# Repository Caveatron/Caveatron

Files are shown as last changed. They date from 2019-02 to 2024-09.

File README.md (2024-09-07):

# Caveatron

The Caveatron is a unique compact, handheld, electronic device for mapping caves or other underground environments. It functions as a cave survey tool, recording conventional distance, azimuth and inclination measurements and can also go far beyond that with its integrated LIDAR to capture a full 3D scan of the cave interior. It greatly speeds up the cave survey process by recording station-to-station shots in just a few seconds and performs a station-to-station 3D scan traverse in less than a minute. The user can fully interact with the device and review data with the built-in touchscreen. A USB port provides access to the stored data from a PC or Mac and is also used to charge the integrated long-life battery pack. The station measurement file is compatible with Walls Cave Mapping Software and the LIDAR scan file can be quickly processed into a standard point cloud with custom-written software. The Caveatron is designed to be easily portable, lightweight, and low cost as well as water and dirt resistant and durable enough to survive regular use in a cave.

## Key Features

- Survey and 3D scan caves
- 12 m or 30 m LIDAR range at up to 32000 pts/sec
- Laser rangefinder up to 40 m
- Integrated intertial measurement unit including digital compass, inclinometer, and gyroscope
- Position estimation during scanning
- Fast Teensy processor
- File transfer to PC over USB
- Water/dust resistant 3D printed enclosure
- Custom printed circuit board

## What's New (2024-05-03)

Rev C is the current and preferred version and is the only one in active development. This version uses the faster Teensy 4.1 processor and has several enhancements including ability to use the 30m RPLIDAR S2 or 12 RPLIDAR A1M8, a new magnetometer module for much improved compass accuracy and reliability, a capacitive touchscreen, faster battery charging, and a smaller size.
New revisions of the Rev C board (C.3 and C.4) have been posted along with an updated bill of materials. The Rev C assembly documentation has not yet been updated for the new PCBs but is not significantly different.

Rev B is based on the older Teensy 3.6 processor and is now deprecated and some components may no longer be available.

The original, Arduino Due-based version (Rev A) information is all still available and can now be found in the legacy_material_rev-A directory.
In the Rev A version, many people had difficulty with compiling the code in terms of getting all the libraries to work together and getting all the settings right. With the Teensy, it is relatively easy to load a pre-compiled HEX file, avoiding all the software headaches. For now I am just going to provide the HEX file instead of all the code to simplify things, since the code has gotten even more complex in the new version and I am no longer using the Arduino IDE. If you want to work on the code, please contact me directly.

## Summary of Caveatron Directory Contents for each Revision

### Documentation
- Bill of Materials
- Assembly Instructions
- Wire Harness Assembly Instructions
- 3D Printed Parts Description

### PCB
- Schematic diagram
- KiCad files
- PCB gerber files

### Mechanical
- STL files for all 3D printed parts
- STEP files for all 3D printed parts

## These items can be found in other folders:

### Calibration
Info and calculators can be found at https://github.com/Caveatron/Calibration

### Software
Software can be found at https://github.com/Caveatron/Software

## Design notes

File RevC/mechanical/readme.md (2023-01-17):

These STL files contain a full design for the new Caveatron Rev C enclosure with either an RPLIDAR S2 or RPLIDAR A1M8. All parts have been printed and tested. STEP files are also provided for customization.

Two versions exist of the RPLIDAR S2 lid. The DOME version uses an acrylic dome to ensure a fully protective and waterproof cover. This version may reduce the range but has not beeen tested to detemine what the effect is. The OPEN version exposes part of the LIDAR head and uses a gasket to seal against to RPLIDAR body. This provides an unobstructed view from the LIDAR and it may provide a waterproof seal as well but has not been tested and does leave the LIDAR partially exposed to impacts. 

Similarly, two versions of the RPLIDAR A1M8 lid are provided including one with windows and one that only has metal corner posts but leaves the sides open to minimize obstructions and prevent distortions. The open version only provides impact protection as it will allow dust, mud or water into the enclosure. 

A detailed assembly document will be uploaded when completed.

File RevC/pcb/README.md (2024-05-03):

# Caveatron Printed Circuit Boards (PCBs)

This folder provides the files needed to create PCBs for the Caveatron. I use PCBWay for fabrication and the Gerber files are setup for their requirements. For each board version, the following are providedL
- Gerber files: Send these to the PCB fabricator to get your board produced. Nothing else should be needed.
- Kicad files: The files for the schematic and board layout if you need to make an edit.
- PDF of the circuit schematic

## What is the difference between the PCB revisions?

### Rev C.4
This is the preferred board version. Use this one for most builds.

### Rev C.3
Use this version if want to use the Pololu MinIMU or AltIMU modules to provide all of the IMU data and not use the RM3100. This is lower cost but will result in lower quality azimuth data. You can also use this version if you want to use the MinIMU or AltIMU modules to provide just the accelerometer and gyroscope data alongside using the RM3100 for the magnetometer.

### Rev C.2
Use this version if you want to use a coin cell battery to maintain the RTC, although the battery will have to be replaced every 6 weeks. Can be upgraded to replace coin cell with modification. It is otherwise the same as C.3. Not recommended.

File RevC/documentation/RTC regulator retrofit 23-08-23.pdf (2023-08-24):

## RTC Regulator Retrofit for Caveatron/Caveatron SV Rev C

### Version: 2023-08-23

Background

The Teensy 4.1 Real-Time Clock (RTC) draws much more current than the one in the Teensy 3.6 (46uA vs 1.6uA). As a result, the CR1220 battery used for backup power will only last about 6 weeks. Since such frequent replacement is undesirable, I have created a retrofit for the Rev C Caveatron and Caveatron SV that replaces the battery with a small voltage regulator that ties directly to the main battery. Without recharge, this will keep the RTC powered for more than 5 years. Although the RTC is nominally powered by 3V, it runs fine to below 2.7 V. Since 2.8V is the nominal cutoff for the main battery, that was selected for the voltage regulator. The one used has a very low drop out voltage that is nearly the same as its output voltage when at or below 2.8V, so can be used all through the main battery’s voltage range.

The required materials are in the table at the end of this document. The circuit is shown below and contains a simple voltage regulator, two capacitors and input/output pins. The 1 uF ceramic capacitors are placed across the input and output terminals of the regulator for stability. A JST connector is used for the input voltage which is provided by wires that are soldered to the input of the battery charger module. The circuit board will be soldered to the pads that were used for the coin cell battery holder to provide the output voltage to the RTC. Two right angle header pins on either side of the board are used for this purpose (two on each side allow it to sit flat on the board and make it easier to solder.)

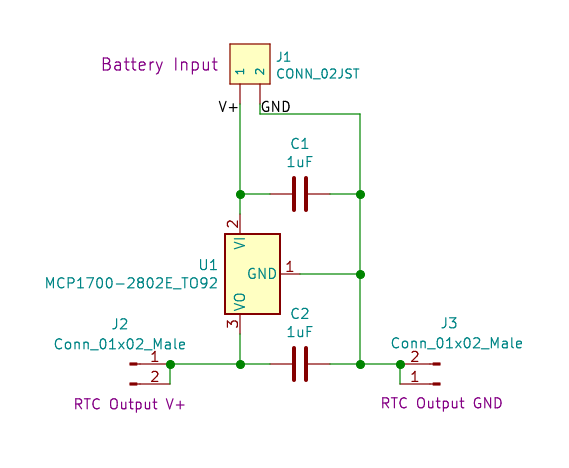
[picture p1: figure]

Assemble the voltage regulator board

1. Cut a piece of protoboard to 0.6 x 0.6 inches, cutting between the holes

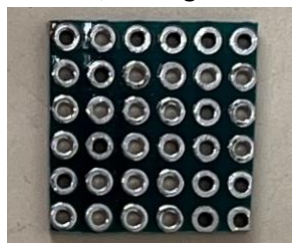
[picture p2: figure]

2. Insert the regulator and capacitors through the holes on the protoboard as shown in the photo. Be sure that the regulator flat is oriented correctly. When looking at the regulator from the flat side, the ground pin is on the left.

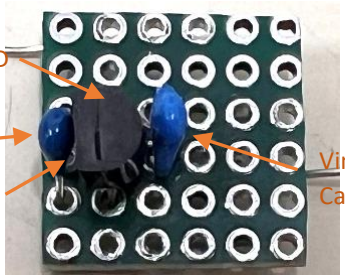
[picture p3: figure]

3. On the underside of the protoboard, bend the pins and wrap them together as shown in the photo below with the pin wires labeled. Be sure the pins are bent to pass adjacent to the holes that will be used for the right angle headers (orange circles) and the JST connector (blue circles).

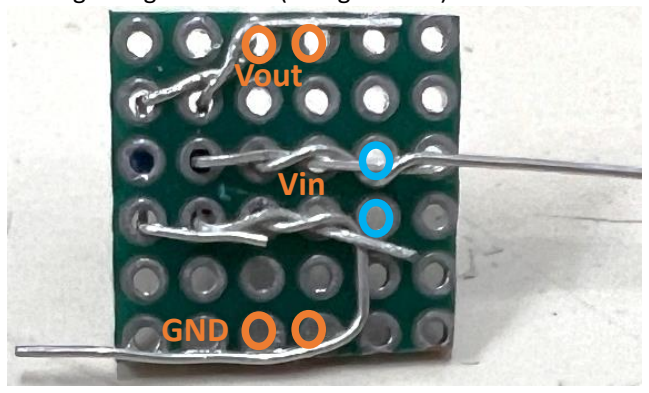
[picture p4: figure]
GND; Vin; Vout

4. Solder the wrapped pin wires together.
5. Cut the right angle headers so you have two sets with two pins each.
6. Slide the plastic standoff on the header down to where it is near the end of the pin
7. Insert the right angle headers into the center two holes on opposite edges of the board as shown in the photo below. Be sure the right angle part is underneath the board and the plastic standoffs are sticking out. Also be sure the pin wires from the components are touching the header pins on the underside of the board
8. Ensuring the right angle header pins are not angled to the board and sticking straight out, solder them to the wire pins.

### Regulator Flat

### GND

### Vin to GND Capacitor

### Vout to GND Capacitor

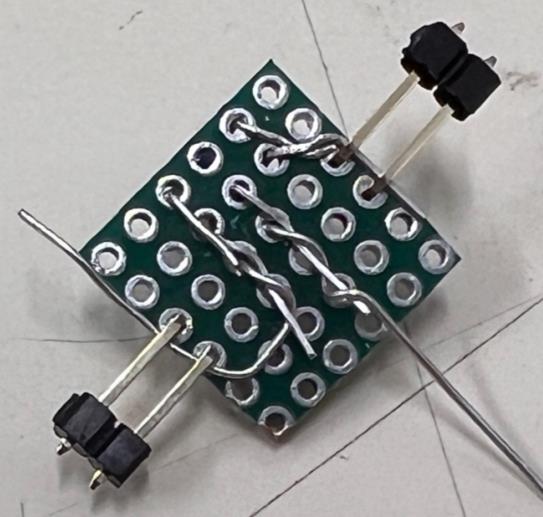
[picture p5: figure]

9. Insert the JST socket – be sure it is oriented so that the red wire on the connector will connect to the voltage input of the regulator (center pin when viewed from the flat side.)
10. Solder the JST socket pins to the pin wires on the underside of the board. Trim off any excess wire.
11. If desired, you can test the board by applying 3-5V on the JST connector and confirming 2.8V is present between the two sets of right-angle header pins
12. Cut the right angle header pins to remove the plastic standoff and shorten them so that the length beyond the board is about 0.1” as shown in the photos below.

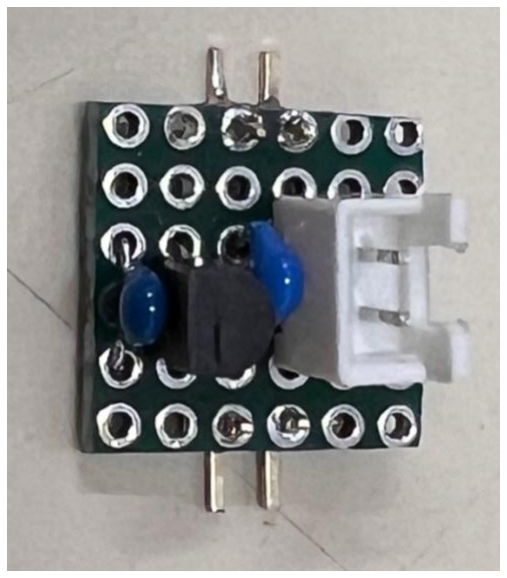
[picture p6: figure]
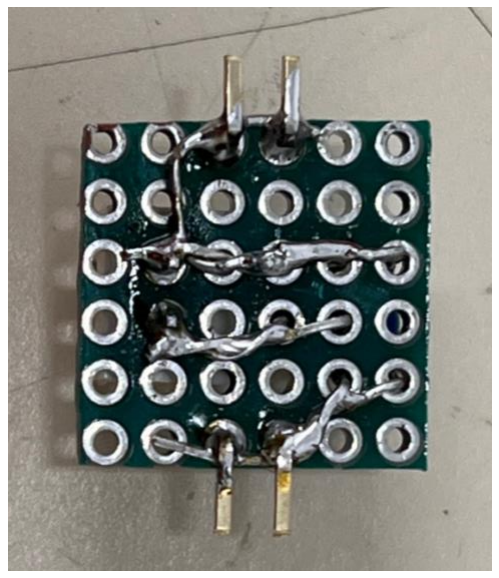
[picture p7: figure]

Finished RTC regulator board

Replace the coin cell battery holder

1. Using a small flathead screwdriver, gently pry on the inside of the coin cell battery holder [A in figure below] while holding the soldering iron on the pad until it comes up from the solder. The pull up on the holder while holding the soldering iron on the other side until it come free. Clean up excess solder on the RTC coin cell pads.

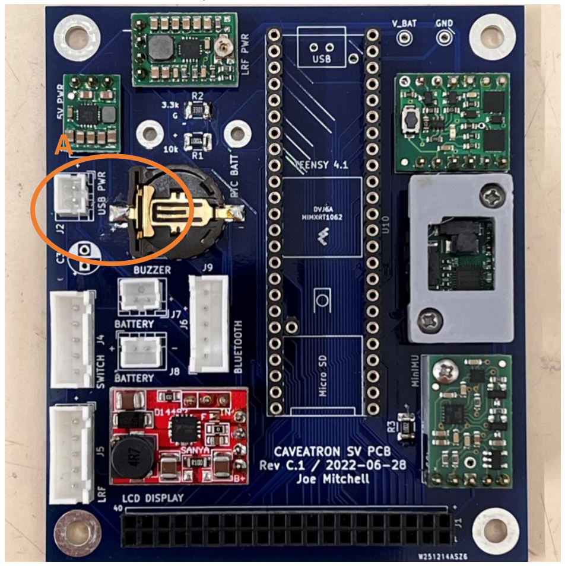
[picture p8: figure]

Caveatron SV PCB before modification. The location on the regular Caveatron is different but the process is the same.

2. Position the regulator circuit across the pads [B (Vout) & C (GND) in the figure below] and center the header pins on the pads as best as possible. Verify that the ground of the regulator board is toward the negative RTC pad [C] (the pad to the left when looking toward the flat of the regulator.)
3. Holding the circuit board in place, solder it to the RTC pads.

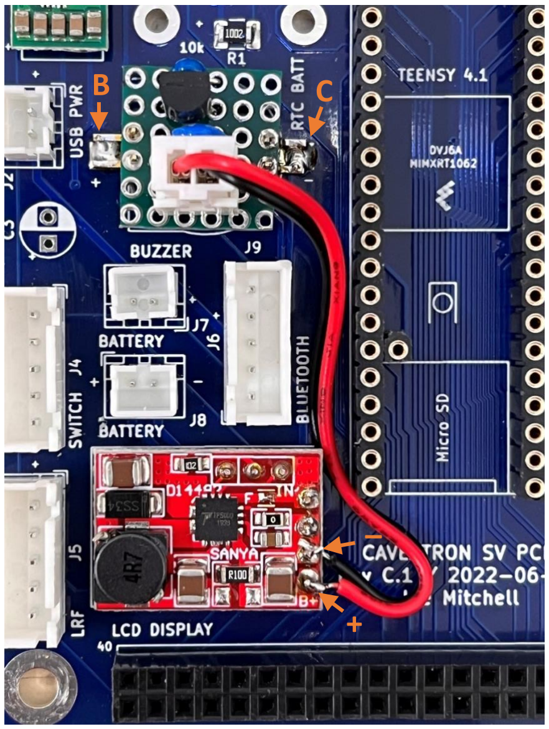
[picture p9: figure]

Installed RTC regulator board connected to the battery.

Connect to the supply voltage

1. Locate the battery charger module. The two indicated pins [+, -] on the illustration above are connected directly to the battery.
2. Place the black wire touching the GND input pin [-] on the top of the battery charger module and carefully solder it so that it does not touch any other pad or pin.
3. Repeat with the red wire on the Vin pin [+].
4. Check that the connection is good and that you have the battery voltage (3-4.2V) on the JST connector.
5. Plug the JST connector into the voltage regulator board.

Turn on the Caveatron and set the time in the Data and Time Settings menu. Power it off, wait a minute and then turn it back on. If the time is correct, then the fix is working properly.

Bill of Materials

Item | Qty | Manufacturer | Mfr. P/N | Description | Suggested Vendor Link | Photo

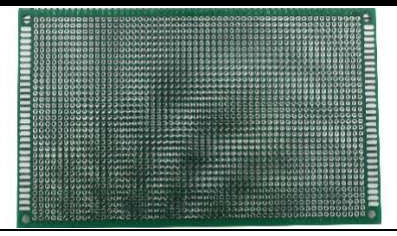
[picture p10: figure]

Prototype Circuit Board | 1 | Various | N/A | JST 2.54mm pitch, 5 pin, male connector | Many sources

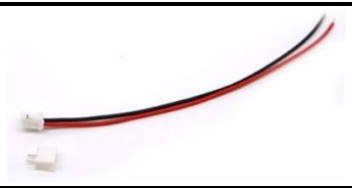
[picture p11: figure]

Notes: Cut to 0.6 x 0.6” size JST
Connector
2-pin
1 | Various | JST-XH | JST 2.54mm pitch, 2 pin, socket and prewired plug

Many
sources

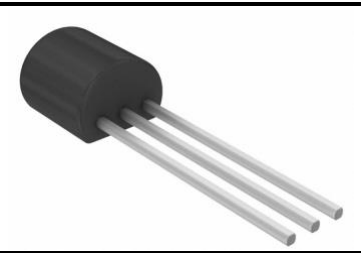
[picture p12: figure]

Notes: Connector for input voltage. 2.8V
Voltage
Regulator

1 Microchip Technology

MCP1700-
2802E/TO

Linear voltage
regulator IC, 2.8V,
250mA, TO92

Digikey (https://www.digikey.com/en/products/detail/microchip-technology/MCP1700-2802E-TO/2614902)

Notes:
1uF Ceramic
Capacitor
2 | TDK | FG18X7R1E 105KRT06

Ceramic Capacitor,
1uF, 25V, Radial
leads

Digikey (https://www.digikey.com/en/products/detail/tdk-corporation/FG18X7R1E105KRT06/5802875) (and
many
others)

Notes: Most any ceramic capacitor of 1 uF will work so long as it is rated to 6V or higher. Right angle
male header
pins
4 | Various | N/A | 2.54mm pitch | Many sources

Notes: Need 2 sets of 2 to connect to the Caveatron PCB for the output voltage

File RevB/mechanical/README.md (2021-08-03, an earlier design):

# 3D Printed Parts

This directory contains solid model files for 3D printed Caveatron parts

## NOTE: All STL files must be scaled by 2540% in your slicer software to produce correctly printed parts! Additional information can be found in the 3D Printed Parts Description file under Documentation.

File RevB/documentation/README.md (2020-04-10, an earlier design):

# Documentation

This directory contains documentation about building and setting up the Caveatron - Rev B.

## Files

- Bill of Materials - Listing of Caveatron parts and sources.
- Assembly Instructions - Detailed instructions for building the Caveatron.
- Wire Harness Assembly - Instructions for preparing the wire harnesses.
- Caveatron Setup & Calibration Instructions - Detailed instructions for initial setup with the Caveatron_Setup software and for calibration of the hardware prior to use.
- Calibration Calculators - Excel spreadsheets used to perform calibrations of the magnetometer, accelerometer, gyroscope, and for correction of LIDAR window distortions.

## Alternate RPLIDAR Modification Instructions

This file contains an alternative hardware-based approach, contributed by Szymon Kostka, to avoid window distortions when using the RPLIDAR and allows the use of a cylindrical window without obscuring corners. It requires a different LIDAR enclosure design than the one provided on this site.

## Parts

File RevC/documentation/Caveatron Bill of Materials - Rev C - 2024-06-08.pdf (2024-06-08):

### Caveatron Bill of Materials

Hardware Revision: C

### Date: 2024-06-08

Item | Qty | Manufacturer | Mfr. P/N | Description | Suggested Vendor Link | Photo
Main Processor | 1 | PJRC Electronics | Teensy 4.1 | Teensy 4.1 | PJRC Store (https://www.pjrc.com/store/teensy41_pins.html)

Notes: The main system processor. Available from multiple vendors. Versions with and without the pins pre-installed are available (link above is with pins). Either of the versions (with or without Ethernet) are fine.
Touchscreen
LCD
1 | BuyDisplay | N/A | LCD 3.5” 320x480 TFT Display Module, OPTL Touch Screen w/Breakout Board
| | | Choose these options: -Capacitive touch panel -16-bit 8080 40-pin header -3.3V supply -No font chip

BuyDisplay (https://www.buydisplay.com/lcd-3-5-inch-320x480-tft-display-module-optl-touch-screen-w-breakout-board)

Notes: The display and user interface. Note that this is the capacitive touchscreen version unlike the resistive version used previously.

Item | Qty | Manufacturer | Mfr. P/N | Description | Suggested Vendor Link
Photo
Laser Rangefinder | 1 | JRT Meter Tech., Co, Ltd. | Unknown | 40m – 60m Laser Distance Sensor Module | Egismos (https://www.egismos.com/laser-measuring-optoelectronics-module/laser-range-finder-distance-meter-4M) (HEX) Ebay (https://www.ebay.com/itm/254161557105) (ASCII) Alibaba (https://www.alibaba.com/product-detail/M88B-40m-Cheap-OEM-Chengdu-JRT_60644767746.html) (HEX) Alibaba (https://www.alibaba.com/product-detail/M88B-60m-Measuring-Sensor-Range-Finder_1600250111785.html) (HEX) Alibaba (https://www.alibaba.com/product-detail/Laser-Distance-Manufacturers-JRT-Smart-Distance_1600062036577.html) (probably HEX)
| | | | | Availability changes frequently. Sites linked above has availability as of the date of this BOM

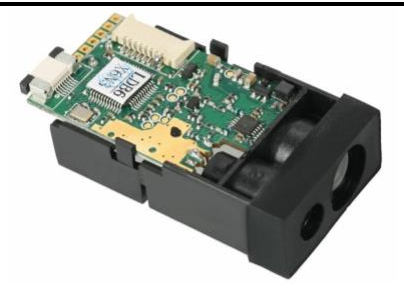
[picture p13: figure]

Notes: Used for station distance measurements. There are several variants of this module including those that use ASCII or HEX-based commands both of which are supported by the Caveatron. Based on the datasheets I have reviewed I think any variant of this style should work. This style is the preferred LRF module and the only one for which the Rev C enclosure is designed to accommodate.

IMU Selection Options Summary for the parts on the next page – listed for each PCB board version (Options listed in order of preference)

PCB Rev C.4
Witmotion RM3100 and LSM6DS33

PCB Rev C.3 and PCB Rev C.2
Option #1: Witmotion RM3100 and Pololu MinIMU-9 v5 Option #2: Witmotion RM3100 and Pololu AltIMU-10 v5 Option #3: Pololu MinIMU-9 v5 only
Option #4: Pololu MinIMU-10 v5 only

Item | Qty | Manufacturer | Mfr. P/N | Description | Suggested Vendor Link | Photo
Compass Module HIGHLY RECOMMENDED Used in PCB Rev C.2 (optional), C.3 (optional), C.4 (required) | 1 | Witmotion | RM3100 | WitMotion High-Precision RM3100 Military-grade Magnetometer Sensor | Amazon (https://www.amazon.com/High-Accuracy-Magnetometer-Geomagnetism-Military-Grade-High-Revolution/dp/B01N5QL0XC/) or Witmotion (https://www.wit-motion.com/geomagnetic-sensor/witmotion-high-precision-rm3100-military.html)

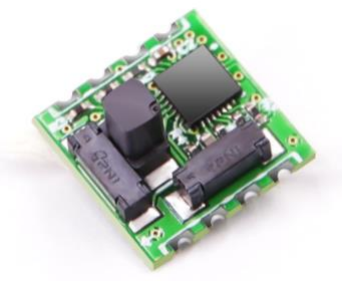
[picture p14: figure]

Notes: Used to determine the azimuth angle of the Caveatron. This is the best currently available low-cost magnetometer module option. This magnetometer has proven more accurate, reliable and with less drift than another other tested. It must be used with one of the IMU modules below that contain an accelerometer and gyroscope.

IMU Module 1

Used in PCB Rev
C.2, and C.3. Is not
used with C.4
1 | Pololu | MinIMU-9 v5 (#2738)
| | Or
| | AltIMU-10 v5 (#2739)

MinIMU-9 v5 Gyro,
Accelerometer, Compass
(LSM6DS33, and LIS3MDL
Carrier)

Pololu (https://www.pololu.com/product/2738)

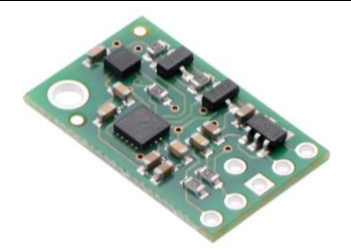
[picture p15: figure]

Notes: Used to determine orientation of the Caveatron and measure inclination. Only used in PCB Rev C.3 and C.4. Can be used with or without the RM3100. The AltIMU-10 v5 is an equivalent part and can also be used (the altitude sensor is not used). The MinIMU-9 and AltIMU-10 v3 and v4 are still supported by the code and electronics but are no longer available.

IMU Module 2

Used in PCB Rev
C.4 only
1 | Pololu | #2736 | LSM6DS33 3D Accelerometer and Gyro Carrier with Voltage Regulator

Pololu (https://www.pololu.com/product/2736)

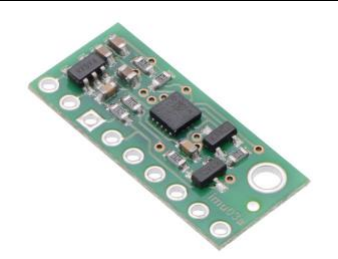
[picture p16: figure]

Notes: Used to determine inclination and roll angle of the Caveatron. This part is used only in PCB Rev C.4 and must be used with the RM3100.

See summary of these combination options on the previous page.

Item | Qty | Manufact urer | Mfr. P/N | Description | Suggested Vendor Link | Photo

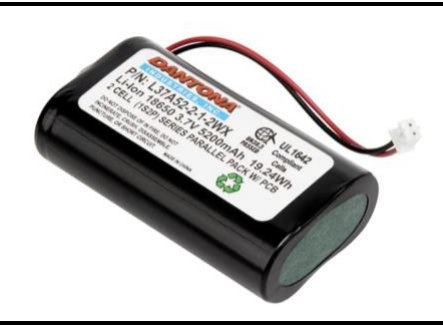
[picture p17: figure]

Battery Pack OPTION 1 | 1 | Dantona Industries | L37A52-2-1-2WX | Li-Ion Battery Pack, 3.7V, 5200 mAh, 18650, wire leads with connector | Digikey (https://www.digikey.com/en/products/detail/dantona-industries/L37A52-2-1-2WX/13692687)

Notes: Primary system battery. This one is the best choice since it is lower cost and already has a connector. Battery Pack

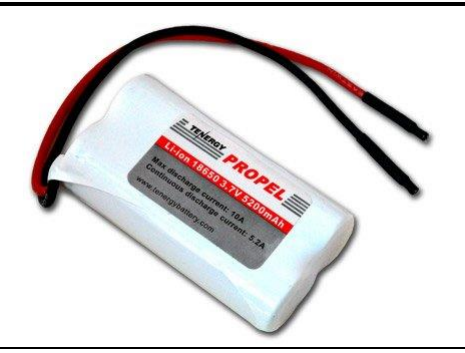
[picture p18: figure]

OPTION 2

1 | Tenergy | 31001 | Tenergy Li-Ion 18650 3.7V 5200mAh Rechargeable Battery PCB module with Bare Leads

Tenergy (https://power.tenergy.com/tenergy-li-ion-3-7v-5200mah-rechargeable-battery-w-pcb-1s2p-19-24wh-6a-rate/)

Notes: Primary system battery. Identical size and capacity to Option 1, but more expensive and you must add a connector.

Font/Graphics
IC
1 | Winbond | W25Q128JVSIM | W25Q128 SPI flash memory IC, 128 Mbit, quad 8-SOIC

Digikey (https://www.digikey.com/en/products/detail/winbond-electronics/W25Q128JVSIM/6819721)
and many other source

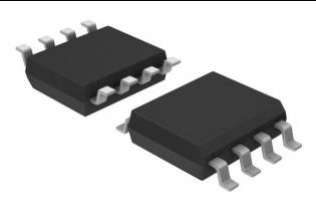
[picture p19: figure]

Notes: Contains the fonts and graphics used for the GUI. You must use the 128Mbit 8-SOIC package version – other capacities may not work. It is soldered to the pad location on the underside of the Teensy 4.1 that is directly under the micro-SD slot and closest to the edge.

Item | Qty | Manufacture r | Mfr. P/N | Description | Suggested Vendor Link | Photo
Battery Charger Module | 1 | Unknown | TP5000 | Lithium Ion 3.7V Charger Module | Amazon (https://www.amazon.com/Comimark-Charger-Lithium-LiFePO4-Charging/dp/B07XM7WT5M)

Notes: Battery charging module. There are several sources for this module and at least 2 variants. Be sure to get the variant with the 4 power pins all on the same side. A solder bridge is required to make it functional and a 0.2 ohm resistor can be added to increase the charge current above 1 Amp. These are usually on a red PCB but can also be green from other sources.
10k resistor | 2 | Various | Various | SMD resistor, 10k-ohm, 1%, 1206 package

Digikey (https://www.digikey.com/en/products/detail/stackpole-electronics-inc/RMCF1206FT10K0/1759669)

Notes: Resistor for battery monitor voltage divider and for IMU power input. Available from numerous manufacturers and vendors - the above is only 1 example. ¼ watt or less is fine since this carries no significant current.
3.3k resistor | 1 | Various | Various | SMD resistor, 3.3k-ohm, 1%, 1206 package

Digikey (https://www.digikey.com/en/products/detail/stackpole-electronics-inc/RMCF1206FT3K30/1753917)

Notes: Resistor for battery monitor voltage divider. Available from numerous manufacturers and vendors - the above is only 1 example. ¼ watt or less is fine since this carries no significant current.
0.2-ohm
resistor
OPTIONAL
1 | Various | Various | SMD resistor, 0.2-ohm, 1%, 0.5W, 1206 package

Digikey (https://www.digikey.com/en/products/detail/stackpole-electronics-inc/CSR1206FKR200/1742391)

Notes: Resistor for battery charger module. Only needed if you want to increase the charge current of the TP5000 from the default 1 Amp to 1.5 Amp.

Item | Qty | Manufactu rer | Mfr. P/N | Description | Suggested Vendor Link | Photo
Voltage Regulator – 5V | 1 | Pololu | 2119 | 5V Step-Up/Step-Down Voltage Regulator S7V7F5 | Pololu (https://www.pololu.com/product/2119)

Notes: Power supply for Teensy. LRF Voltage
Regulator

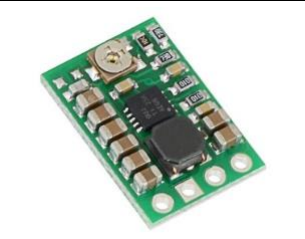
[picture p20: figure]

1 | Pololu | 2118 | Pololu Adjustable Step- Up/Step-Down Voltage Regulator S7V8A

Pololu (https://www.pololu.com/product/2118)

Notes: Power supply for Laser Rangefinder. Output needs to be set to 3.0V. LIDAR Voltage
Regulator


ONLY USED
FOR
RPLIDAR
A1M8
1 | Pololu | 2123 | Pololu 5V Step-Up/Step- Down Voltage Regulator S7V8F5

Pololu (https://www.pololu.com/product/2123)

Notes: Power supply for RPLIDAR A1M8. This cannot source enough current for the RPLIDAR S2. LIDAR Voltage
Regulator

REQUIRED
FOR
RPLIDAR S2
(can be used
with any
LIDAR)
1 | Pololu | 2891 | Pololu 5V Step-Up Voltage Regulator U3V70F5

Pololu (https://www.pololu.com/product/2891)


Notes: Power supply for RPLIDAR S2. Higher current alternative to the regulator above - needed for the S2. Can also be used with the A1M8 or other LIDAR modules.

Item | Qty | Manufacturer | Mfr. P/N | Description | Suggested Vendor Link | Photo


Power Switch Module | 1 | Pololu | 2808 | Mini Pushbutton Power Switch with Reverse Voltage Protection, LV | Pololu (https://www.pololu.com/product/2808)

Notes: Turns on and off system power when pushbutton power switch is pressed and also controls timed auto power-off. Piezoelectric
Buzzer


1 | Uxcell | A14062400ux0199 | uxcell A14062400ux0199 5 Pcs DC 2-28V 80Db Sound Electronic Passive Buzzer Alarm Black, 22 x 4.5 mm

Amazon (https://www.amazon.com/gp/product/B01AJOESXG)

Notes: Indicator buzzer.
2.8V Voltage
Regulator

USED IN PCB
REV C.3 and
C.4
(or to upgrade C.2)
1 | Microchip Technology

MCP1700-
2802E/TO

Linear voltage regulator IC, 2.8V, 250mA, TO92

Digikey (https://www.digikey.com/en/products/detail/microchip-technology/MCP1700-2802E-TO/2614902)


Notes: Regulates battery voltage to keep Real Time Clock active when Caveatron is turned off. Replaces coin cell battery used in PCB Rev C.2. 1uF Ceramic
Capacitor
USED IN PCB
REV C.3 and
C.4
(or to upgrade C.2)
2 | TDK | FG18X7R1E105K RT06

Ceramic Capacitor, 1uF, 25V, Radial leads

Digikey (https://www.digikey.com/en/products/detail/tdk-corporation/FG18X7R1E105KRT06/5802875) (and
many others)

Notes: Stabilizes output voltage of RTC regulator above. Most any ceramic capacitor of 1 uF will work so long as it is rated to 6V or higher.

Item | Qty | Manufacturer | Mfr. P/N | Description | Suggested Vendor Link | Photo
| | Adafruit | 3350 | | Adafruit (https://www.adafruit.com/product/3350) Amazon (https://www.amazon.com/Momentary-Tri-Color-Button-Illuminated-Stainless/dp/B09FDD9KR9)

Power Switch
& Charging
LED

1

Rugged Metal Pushbutton -
16mm RGB Momentary

CIT Relay and
Switch
BH16NBSBG | Digikey (https://www.digikey.com/en/products/detail/cit-relay-and-switch/BH16NBSBG/12503457)


Notes: On/Off power switch and charge indicating ring LED. This one enables separate colors on the ring LED for indicating charging and charge complete. These can be found at other sources as well but if you buy from another source be sure to get a common anode version.us
USB Jack | 1 | GT Contact | GT11A200-10 (RR-11A200-10)

Micro USB-B Plastic Panel
Mount to 6 Pin Solder Type

USBFirewire.
com (https://www.usbfirewire.com/parts/rr-11a200-10.html)


Notes: USB jack for data download, battery charging, and loading of software and calibration parameters. This is the version with the solder pins on the back side. If you prefer a USB-mini connector, that is available as part number RR-114200-10 (https://www.usbfirewire.com/parts/rr-114200-10.html) and is an identical fit.

Item | Qty | Manufacturer | Mfr. P/N | Description | Suggested Vendor Link | Photo


USB Cap | 1 | GT Contact | GT1C522122 (RR-1C522122) | Seal Cap | USBFirewire. com (http://www.usbfirewire.com/parts/rr-1c522122.html#RR-1C522122)

Notes: Waterproof cap for USB jack. This cap works for either the mini or micro USB options.

Item | Qty | Manufacturer | Mfr. P/N | Description | Suggested Vendor Link | Photo
MicroSD Card | 1 | Various | Various | SanDisk 32GB Ultra microSDHC UHS-I Memory Card | Amazon (https://www.amazon.com/dp/B073JWXGNT/) and many other sources

Notes: Storage for Caveatron data. Numerous brands and sources available. MicroSD card must be SDHC type not larger than 32 GB (smaller capacities are fine as well). SanDisk brand is preferred as they are generally the most reliable.

Teensy USB
connector
1 | N/A | N/A | Micro USB Male Solder Connector

Amazon (https://www.amazon.com/Micro-USB-Connector-Conwork-Replacement/dp/B072MCHGXK)
and many other
sources

Notes: For the cable to connect the exterior USB jack to the Teensy. Wires are soldered between this part and the USB jack connector pins. Note that only the D+, D-, and GND are connected on this plug. The USB power (and a second GND wire) goes from the USB jack to a plug on the main PCB.

LCD
Connector
Cable
1 | N/A | N/A | 40 pin IDE Male to Female Extension Cable, 4” (10 cm) or 6” (15 cm)

Ebay (https://www.ebay.com/itm/170709721128)

and other sources

Notes: Cable to connect to LCD Touchscreen from the Caveatron main board. Cables longer than 6” would take up too much space in the enclosure while those shorter than 4” are not long enough. These are available from multiple vendors. Note that some of these connectors do not include one of the middle pins, however those are fine since that pin is not used.

Item | Qty | Manufact urer | Mfr. P/N | Description | Suggested Vendor Link | Photo
JST Connector 5-pin | 2 or 3 | Various | JST-XH | JST 2.54mm pitch, 5 pin, male connector | Amazon, Ebay and others

Notes: Connector for LRF, power switch, and LIDAR. If you order them prewired as in the photo, be sure they are at least 100 mm in length. JST
Connector
2-pin
3 or 4 | Various | JST-XH | JST 2.54mm pitch, 2 pin, male connector

Amazon, Ebay and
others

Notes: Connector used for USB data, USB power, piezo buzzer, and battery. If you order them prewired as in the photo, be sure they are at least 100 mm in length. (You won’t need one for the battery if you order a battery that is pre-connectorized.
Socket
Headers 1

1
(6 pin
positions
needed)

Prec-Dip or
others

310-87-
106-41-
001101

Socket header, 0.1” pitch, 4.2 mm insulation height,
single row, 6 pins

Digikey (https://www.digikey.com/en/products/detail/preci-dip/310-87-106-41-001101/3757345)
and others

Notes: Header sockets for RM3100 magnetometer. Only needed if you are using the RM3100. Short header needed since the RM3100 has tall components. This header size is matched to the RM3100 brackets. Other variants with different numbers of pins are available. 4 pins are needed on one side and 2 pins on the other.
Socket
Headers 2

3
(54 pin
positions
needed)

Prec-Dip or
others

801-87-
024-10-
001101

Socket header, 0.1” pitch, 7.0 mm insulation height,
single row, 24 pins

Digikey (https://www.digikey.com/en/products/detail/preci-dip/801-87-024-10-001101/3757459)
and others

Notes: Header sockets for Teensy and IMU. Optional but this shorter size is preferred over the more common 8.51mm height to avoid interference with the display. Other variants with different numbers of pins are available. Two sets of 24 pins and 1 additional pin are needed for the Teensy and 5 pins are needed for the IMU module.

Item | Qty | Manufacturer | Mfr. P/N | Description | Suggested Vendor Link | Photo
Screen Protector | 1 | Supershieldz | N/A | iPhone SE and iPhone 5 Screen Protector | Amazon (https://www.amazon.com/gp/product/B00EOYMO66/)

Notes: Protection film for touchscreen. Needs to be cut to length. Most any PET screen protector film for iPhone 4, 4S, 5, 5s, or SE should work as they have the same screen width as the 3.5” LCD. Multiple vendors produce a similar product.
Laser
Rangefinder
Optical
Filter
1 | Rosco | 299 | Roscolux 1.2 Neutral Density Filter, 20x24”

Adorama (https://www.adorama.com/ro299.html)

Notes: Optical filters for the LRF receiver to only accept readings from the retroreflective card. This filter only has half the optical density required, so must be folded in half when installed. Other neutral density films are fine so long as they are sufficiently dark to prevent the LRF from getting a signal from a non-retroreflective surface but no so dark that they reduce the range from the retroreflective surface.
RTC Battery Holder

NOT
RECOMMENDED
Only used with
PCB Rev C.2

1 MPD and
others

BC501SM Coin Cell Battery Holder -12mm
(for CR1220 batteries)

Digikey (https://www.digikey.com/en/products/detail/mpd-memory-protection-devices/BC501SM/2439260)

Amazon (https://www.amazon.com/QMseller-CR1220-Horizontal-Battery-Container/dp/B07GXTQN75)

Notes: Holds a CR1220 battery to provide power to maintain the Real-time clock on the Teensy. The CR1220 batteries can only run the real-time clock for 6 weeks so require frequent replacement. A mod has been implemented to replace this part with a regulator and this part has been removed from PCB C.3 and C.4. Identical holders are available from many sources with differing part numbers.

Item | Qty | Manufacturer | Mfr. P/N | Description | Suggested Vendor Link | Photo
LIDAR OPTION 1 | 1 | Slamtec | RPLIDAR A1M8 | LIDAR 360 Degree Laser Range Scanner, 12 m range | Robot Shop (https://www.robotshop.com/en/rplidar-a1m8-360-degree-laser-scanner-development-kit.html)

Notes: Scanning LIDAR sensor. Other models that should also work but have not been tested include RPLIDAR A2M6, A2M7, A2M8, and A3. These LIDARs are triangulation-based. Available from several sources.
LIDAR

OPTION 2

1 | Slamtec | RPLIDAR S2

LIDAR 360 Degree Laser
Range Scanner, 30 m range

RobotShop (https://www.robotshop.com/en/rplidar-s2-360-laser-scanner-30-m.html)

Notes: Scanning LIDAR sensor. The S2 has 2.5x the range, can collect 4x the number of points per second, has a faster rotation rate, and is smaller, but is more expensive. This LIDAR is a time-of-flight LIDAR. Available from several sources. Watch out since there are several variants out there. A true unit may also be referred to as an S2 R2. Some models which are referred to as S2L are about $100 cheaper than a true S2, but can only get about 12 m of range. There is also an Ethernet version – the S2E but you don’t want that version either. Also there may be some defective units out there as the first one I received only reached 14m even through it appears to be a true S2.

Item | Qt y | Manufacturer | Mfr. P/N | Description | Suggested Vendor Link | Photo


Threaded Inserts for Enclosure | 10 | Initeq | | #6-32 Threaded Heat Set Inserts for 3D Printing (Long) | Ebay (https://www.ebay.com/itm/20-pcs-6-6-32-Threaded-Heat-Inserts-for-3D-Printing-Plastic-Metal-6-32-Long/292301193578)

Notes: Heat set threaded inserts used in 3D printed enclosure. Threaded
Inserts for
external
mounting
(Optional)
1 | Initeq | #1/4-20 1/4" Threaded Heat Set Inserts for 3D Printing (Short)

Ebay (https://www.ebay.com/itm/20x-1-4-20-Brass-Threaded-Heat-Set-Inserts-for-Plastic-3D-Printing-Brass-Metal/292349851049)


Notes: Heat set threaded inserts used in 3D printed enclosure for external mounting. This is an optional part if you plan to attach something external to the Caveatron (like a handle) or mount it to a tripod.
Threaded
Inserts for
RPLIDAR
A1M8
Standoffs

For
RPLIDAR
A1M8 only
4 | Initeq | INM2504 | M2.5-0.4 M2.5 Threaded Heat Set Inserts for 3D Printing (Long)

Ebay (https://www.ebay.com/itm/Qty-20-M2-5-2-5mm-M2-5-0-4-Long-Threaded-Heat-Set-Screw-Inserts-for-3D-Printing/292173883697)


Notes: Heat set threaded inserts used in 3D printed LIDAR enclosure for RPLIDAR A1M8 standoffs. The standoffs that screw into these are included with the RPLIDAR.

Item | Qty | Manufacturer | Mfr. P/N | Description | Suggested Vendor Link | Photo
LIDAR Window OPTIONAL For RPLIDAR S2 only | 1 | JMX | N/A | 3.1” Acrylic Dome | Amazon (https://www.amazon.com/JMX-Replacement-Security-Skylight-Transparent/dp/B07KGFTHL3)

Notes: Window for the RPLIDAR S2. This will only work for a TOF type LIDAR. Curved windows do not work with triangulation LIDARs like the A1 series. The RPLIDAR S2 can be used without this window using a special cover available in the 3D printed parts. However, if you plan to use the LIDAR is a very wet cave, this cover is recommended.
LIDAR
Window

For
RPLIDAR
A1M8 only
1 | Various | N/A | Clear Acrylic Sheet, Transparent, 0.118" Thickness
Amazon (https://www.amazon.com/Sibe-R-Plastics-Supply-0-118-Acrylic-Plexiglass/dp/B084VVFMVL)
Amazon (https://www.amazon.com/Enoin-Acrylic-Plexiglass-Transparent-Paintings/dp/B099ZR6BM3)
Amazon (https://www.amazon.com/Zuvas-Plexiglass-Materials-Handcraft-Photography/dp/B09FGG18SJ)

and other
sources

Notes: Transparent acrylic sheet for LIDAR window. This 0.118” transparent acrylic sheet is used for the RPLIDAR A-series windows. Requires cutting to size. Acrylic seems to be the most transparent with the least distortion and defects of the various clear plastics tested, which is important for getting good LIDAR and rangefinder readings. A flat window is required for the A-series triangulation-based LIDAR modules.
LRF Window
Material
1 | Various | | Clear Acrylic Plexiglass Transparent - 3/32" (0.09)
Amazon (https://www.amazon.com/SIBE-PLASTIC-SUPPLY-ACRYLIC-PLEXIGLASS/dp/B01KABUEUO)
Amazon (https://www.amazon.com/Lexan-Sheet-Polycarbonate-Thick-Nominal/dp/B0759V14Q7)

and other
sources

Notes: Transparent acrylic sheet for LRF window on Main Body. A small variation in thickness is acceptable for this part.

Item | Qty | Manufacture r | Mfr. P/N | Description | Suggested Vendor Link | Photo
Strap Attachment Hardware | 1 | 122317 | Hillman Group | D-Ring Hangers | Lowes (https://www.lowes.com/pd/Hillman-4-Pack-D-Ring-Small-Picture-Hangers/3029191) Amazon (https://www.amazon.com/Hillman-Group-122317-D-Ring-Hanger/dp/B000VBDBOU)

Notes: Small D-rings for attaching neck strap. Available from multiple sources and similar parts likely available from other vendors.

Neck Strap | 1 | DOROM | N/A | DOROM Universal Adjustable Slim Shoulder Sling Neck Strap for All Camera DSLR SLR

Amazon (https://www.amazon.com/DOROM-Universal-Adjustable-Shoulder-Camera/dp/B07597VQJM)

Notes: Neck Strap. This neck strap works well, but other options are available. Recommend a nylon camera strap of 52-60” in length and about 3/8” wide in the ends. O-Ring
Seals

4
feet

The O-Ring
Store
N50.103 | 0.103" (2.62mm) Buna-N 50 O-Ring Cord Stock, Black

O-Ring Store (https://www.theoringstore.com/store/index.php?main_page=product_info&cPath=117_527&products_id=40240)

Notes: O-Ring material for seals in main enclosure and LIDAR module. This 50 durometer material is preferred over more readily available 70 durometer since it is softer and can make a tighter seal. Must cut to length and glue ends (this vendor also sells O-ring glue in small quantities.) Other vendors sell similar material.

Other Required Items:
Caveatron Rev C Printed Circuit Board
Single row male headers, 2.54 mm (0.1”) pitch
Double row female headers 2x20 (for 40 pin LCD Connector), 2.54 mm (0.1”) pitch Soldering supplies
6-32 x 1” flat head machine screws (4x)
6-32 x 3/8” flat head machine screws (4x)
6-32 x 3/8” pan head machine screws (4x)
6-32 x 5/8” pan head machine screw (1x)
4-20 x ¼” thread rolling screws (10x)
M4x0.7 x 6mm (or 5mm) pan head machine screws (4x) 4-20 x ½” thread rolling screws (6x)
2-28 x ¼” thread rolling screws (11x)
PETG filament for 3D printed parts
O-Ring grease
O-Ring epoxy
Size 114 O-ring (for the LIDAR-Main body interface or make your own from the O-Ring cord above) Flexible waterproof epoxy sealant
Adhesive-backed foam
Tape (Kapton or cellophane)

Notes: For assembly and electrical interconnections between boards.

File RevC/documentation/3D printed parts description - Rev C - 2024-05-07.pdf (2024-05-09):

## Caveatron Rev C 3D Printed Parts Description

2024-05-07
Introduction
This document includes a description of the 3D printed Caveatron parts, alternate versions and notes on how to print them. Also included is information on how the 3D printed parts go together. Information on how to assemble all the other components is found in the Caveatron Assembly Instructions document.
Scaling
In some Slicer software, these files must be scaled by 2540% though in others, they import correctly.
General Printing Notes
The recommended material for these parts is PETG. Print settings were 0.2 mm resolution and 20% infill. PLA is not recommended as it is not as durable. ABS may work but is more rigid and brittle so screws and inserts may not work as well. Many parts can be printed without support material. There are a few parts where support material is recommended in a few spots and if you have the ability to insert supports only in selected locations, you do not need supports everywhere.

Main Enclosure Base
The main portion of the enclosure containing the bulk of the components. Support material should be used across the LRF window and the center portion of the USB and power button holes on the right side. This part has the acrylic LRF window glued inside the front, supports the D-rings for the neck strap on the rear, and has an optional ¼-20 heat-set threaded insert location on the underside. This version is designed for the small JRT LRF modules (both ASCII or HEX variants use the same form factor) and will not work with other LRF modules.


Print in this orientation


Main Enclosure Lid
The lid supports the LCD touchscreen and provides mounting points for the LIDAR enclosure as well as a sealed feedthrough for the electrical connection. Six heat-set threaded inserts (6-32) are added to this part – four on the inside in the corners to attach to the base, and two on the top for the LIDAR module.


It attaches to the main enclosure base by four 6-32 flathead machine screws that are inserted from the bottom of the main enclosure base up into the lid.

Print in this orientation

LRF Bracket
The LRF module is supported by this bracket which in turn mounts to the inside of the Main Enclosure Base. A single 2-28 thread rolling screw inserted into the countersunk bottom center hole threads into the hole on the underside of the LRF module. The part is then mounted to the Main Enclosure base with two 4-20 thread rolling screws that are inserted into the countersunk holes on either side.

4-20 screws go in here; The Cradle bracket attaches to the LRF; Toward LRF window; Print in this orientation

LRF Clamp

Attaches to the top of the LRF bracket to fully secure the LRF module. Two 2-28 screws through the holes on either side attach to the top of the LRF bracket. The protrusion goes downward.

module via a 2-28 screw through this hole.

Mounts here

Flip over and 2-28 screw go through the holes.

Print in this orientation

RM3100 Bracket
Provides support to the RM3100 magnetometer. 2-28 screws from the underside the main PCB screw into the two centermost holes in this part.


RM3100 Clamp
Hold the RM3100 magnetometer securely to the bracket to prevent movement.


Be sure to get the orientation correct and adjust it so that it does not press on any components on the RM3100 board. The sloped corner goes toward the 40 pin connector for the touchscreen display.

2-28 screw threads
into the RM3100

Print in this orientation

LCD Clamp
Provides additional support to the long side of the LCD modules. Two of these need to be printed.

A 4-20 thread rolling screw inserts through the LCD Clamp into threads into the hole indicated. The clamp is oriented so that the recessed part is down facing the LCD.

4-20 screw inserted through
the LCD Clamp threads in here.

Print in this orientation


Buzzer Clamp
Provides additional support for the piezo buzzer.


Presses against backside of piezo buzzer (which is inserted into a slot at the side of the Main Enclosure Base). The Buzzer Clamp attaches to the Main Enclosure Base via two 2-28 thread rolling screws threaded into mounting points as shown below.

IMU Bracket
There are 3 slightly different versions of this bracket, which secures the IMU to the PCB to avoid rotation or movement. The “MinIMU Bracket” is for the MinIMU or AltIMU modules using 7mm female headers. The “LSM6DS33 Bracket” has a version for the either 7mm female headers or 8.5mm female headers.

This part does not directly attach to any other 3D part but instead attaches between the IMU module and holes in the main PCB. Two 2-28 thread-rolling screws are inserted through the main PCB into the

Print in this orientation | 2-28 screws thread into the two indicated holes

MinIMU/AltIMU version shown


underside. If the LSM6DS33 or the MinIMU is used, the module is attached to the bracket using one screw from the top. If the AltIMU is used then both top screw holes are used.
RPLIDAR S2 Enclosure Base
Base of the LIDAR enclosure which mounts onto the Main Enclosure Lid and into which mounts the RPLIDAR S2 module. Support material should be used around the feedthrough hole/sealing ring.

Print in this orientation

This part mounts to the Main Enclosure Lid via two 6-32 pan head machine screw through holes in the rear of the module into brass inserts in the Main Enclosure Lid and with an additional 6-32 pan head machine screw through the hole inside the sealing ring in the base (next to the cable feedthrough) that is inserted from inside the Main Enclosure Lid and into a captive nut in this part.
RPLIDAR S2 Mounting Plate
This plate connects directly to the RPLIDAR S2 and then mounts inside the LIDAR enclosure base. Note the orienation printed on the backside.

LIDAR mounts on this face

Print in this orientation


RPLIDAR S2 Enclosure Lid – Dome Version
An acrylic dome is epoxied through the opening and sits in the recess around the opening.

This part mounts to the LIDAR Enclosure Base via four 6-32 flat head machine screw through holes in the top of this part into brass inserts in the LIDAR Enclosure Base.

Print in this orientation

This edge is up
when installed


RPLIDAR S2 Enclosure Lid – Open Version
This version allows the LIDAR lens to be exposed to avoid an losses through the dome. It provides some sealing to the LIDAR via an O-ring inserted into the groove right around the LIDAR opening as shown below.

This part mounts to the LIDAR Enclosure Base via four 6-32 flat head machine screw through holes in the top of this part into brass inserts in the LIDAR Enclosure Base.

Print in this orientation

This edge is up
when installed

O-Ring installed
into this groove to
seal to LIDAR

RPLIDAR A1 Enclosure Base
Base of the LIDAR enclosure which mounts onto the Main Enclosure Lid and into which mounts the RPLIDAR A1 module. Support material should be used around the feedthrough hole/sealing ring.

Print in this orientation

This part mounts to the Main Enclosure Lid via two 6-32 pan head machine screw through holes in the rear of the module into brass inserts in the Main Enclosure Lid and with an additional 6-32 pan head machine screw through the hole inside the sealing ring in the base (next to the cable feedthrough) that is inserted from inside the Main Enclosure Lid and into a captive nut in this part.


RPLIDAR A1 Enclosure Lid - Bottom (Window version)
The bottom half of the A1 LIDAR module lid with windows. Cut acrylic windows are epoxied into slots at the top of this part to support the top half of the lid. Support material needs to be used everywhere across the underside of the lip.

This part mounts to the RPLIDAR Enclosure Base via four 6-32 flat head machine screw through holes in the top of this part into brass inserts in the RPLIDAR A1 Enclosure Base.

Print in this orientation

RPLIDAR A1 Enclosure Lid – Top (Window version)
The top half of the A1 LIDAR module lid with windows which is supported by the cut acrylic windows epoxied into the RPLIDAR Enclosure Lid bottom half.


This part is epoxied to the acrylic windows that project from the RPLIDAR A1 Enclosure Lid (Bottom) that are inserted into slots around the underside of the lid and becomes permanently attached to the RPLIDAR Enclosure Lid (Bottom).

Print in this orientation

RPLIDAR A1 Enclosure Lid - Bottom (Non-window version)
The bottom half of the alternate A1 LIDAR module lid that does not include windows in the event you want to obtain a scan without obscurations and are willing to expose the LIDAR to the cave environment. Four 1.5 mm diameter stainless steel posts are cut to 0.8 inches in length and epoxied into the small holes in each corner. Support material needs to be used everywhere across the underside of the lip.


This part mounts to the RPLIDAR Enclosure Base via four 6-32 flat head machine screw through holes in the top of this part into brass inserts in the RPLIDAR A1 Enclosure Base.

Print in this orientation

RPLIDAR A1 Enclosure Lid – Top (Non-window version)
The top half of the alternate A1 LIDAR module lid with windows which is supported by 1.5 mm diameter stainless steel posts epoxied into the holes in each corner.


This part becomes permanently attached to the RPLIDAR A1 Enclosure Lid – Bottom (Non-window version).

Print in this orientation

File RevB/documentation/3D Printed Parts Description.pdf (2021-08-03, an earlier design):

## Caveatron Rev B 3D Printed Parts Description

2021-08-02

### Introduction

This document includes a description of the 3D printed Caveatron parts, alternate versions and notes on how to print them. Also included is information on how the 3D printed parts go together. Information on how to assemble all the other components is found in the Caveatron Assembly Instructions document.

### Scaling

To print properly, these files must be scaled by 2540% in your slicer software.

### General Printing Notes

The recommended material for these parts is PETG. Print settings were 0.2 mm resolution and 20% infill. PLA is not recommended as it is not as durable. ABS may work but is more rigid and brittle so screws and inserts may not work as well. Many parts can be printed without support material. There are a few parts were support material is recommended in a few spots and if you have the ability to insert supports only in selected locations, you do not need supports everywhere.


### Main Enclosure Base

The main portion of the enclosure containing the bulk of the components. Support material should be used across the LRF window and the center portion of the USB and power button holes on the right side. This version is designed for the UT390B LRF and will not work with other LRF modules.

Print in this orientation

### Main Enclosure Lid

The lid supports the LCD touchscreen, the D-rings for the neck strap and provides mounting points for the LIDAR enclosure as well as a sealed feedthrough for the electrical connections. Two versions of this lid exist – one for the CTE35IPS touchscreen and one for the BuyDisplay 3.5” touchscreen.


It attaches to the main enclosure base by four 6-32 flathead machine screws into brass inserts. Two screws are inserted from the top of the lid in the rear and the two in front are inserted up through the main enclosure base into the lid from below.

Print in this orientation

### RPLIDAR Enclosure Base

Base of the LIDAR enclosure which mounts onto the Main Enclosure Lid and into which mounts the RPLIDAR module. Support material should be used around the feedthrough hole/sealing ring.


This part mounts to the Main Enclosure Lid via two 6-32 pan head machine screw through holes in the rear of the module into brass inserts in the Main Enclosure Lid and with an additional 6-32 pan head machine screw through the hole inside the sealing ring in the base (next to the cable feedthrough) and into a captive nut in the Main Enclosure Lid.

Print in this orientation


### RPLIDAR Enclosure Lid - Bottom (window version)

The bottom half of the LIDAR module lid with windows. Cut acrylic windows are epoxied into slots at the top of this part to support the top half of the lid. Support material needs to be used everywhere across the underside of the lip.

This part mounts to the RPLIDAR Enclosure Base via four 6-32 flat head machine screw through holes in the top of this part into brass inserts in the RPLIDAR Enclosure Base.

Print in this orientation

### RPLIDAR Enclosure Lid – Top (Window version)

The top half of the LIDAR module lid with windows which is supported by the cut acrylic windows epoxied into the RPLIDAR Enclosure Lid bottom half.


This part is epoxied to the acrylic windows that project from the RPLIDAR Enclosure Lid (Bottom) that are inserted into slots around the underside of the lid and becomes permanently attached to the RPLIDAR Enclosure Lid (Bottom).

Print in this orientation

### RPLIDAR Enclosure Lid - Bottom (Non-window version)

The bottom half of the alternate LIDAR module lid that does not include windows in the event you want to obtain a scan without obscurations and are willing to expose the LIDAR to the cave environment. Four 1.5 mm diameter stainless steel posts are cut to 0.8 inches in length and epoxied into the small holes in each corner. Support material needs to be used everywhere across the underside of the lip.


This part mounts to the RPLIDAR Enclosure Base via four 6-32 flat head machine screw through holes in the top of this part into brass inserts in the RPLIDAR Enclosure Base.

Print in this orientation

### RPLIDAR Enclosure Lid – Top (Non-window version)

The top half of the LIDAR module lid with windows which is supported by 1.5 mm diameter stainless steel posts epoxied into the holes in each corner.


This part becomes permanently attached to the RPLIDAR Enclosure Lid – Bottom (Non-window version).

Print in this orientation

### LRF Window Frame

Provides extra backing support for the acrylic LRF window (which is attached with epoxy) and also holds the neutral density filter in the cutout on the front.


This part attaches to the Main Enclosure Base by inserting it into a slot on one side and then affixing it with a 4-20 thread rolling screw through the hole into a mounting point in the front of the Main Enclosure Base as indicated in the drawing below.

Print this side up

4-20 screw threads in here

Rounded end of frame
goes into this slot


### LRF Support Bracket

Provides support to the UT390B LRF module.


Attaches to left rear mounting hole of the LRF module via a 2-28 thread rolling screw inserted up through the hole in the LRF module and is threaded into smaller hole in the LRF Support Bracket. The LRF Support Bracket is affixed to the Main Enclosure Base via a support point on the left side of the enclosure using a 2-28 thread rolling screw inserted through the LRF Mounting Bracket and threaded into the hole in the Main Enclosure Base support as indicated below.

Print this side up

LRF attaches here via 2-28 threaded into this hole; Support Bracket threads in here

2-28 screw inserted through the LRF

### LRF Mounting Post

Provides support to the UT390B LRF module.


This part does not directly attach to any other 3D part but instead attaches between the right rear side of the UT390B LRF and a mounting hole on the main PCB. 2-28 thread rolling screws are inserted through both boards and threaded into this part.

2-28 screw inserted through the LRF module right rear hole threads in here.

2-28 screw inserted through the main PCB LSM303D hole threads in here.

Print this side up

### Battery Charging Board Support Post

Supports the Adafruit Li-Ion Charging Module. Since this module is only held in a couple spots with header pins, this post is needed to give additional support. Either one or two may be used on the left sides of the Charging Module.


This part does not directly attach to any other 3D part but instead attaches between one of the holes on the left side of the Adafruit Li-Ion Charging Module and provided mounting hole on the main PCB. 2-28 thread rolling screws are inserted through the main PCB and threaded into this part. The thin post on top inserts into the hole in the Charging Module and can be mashed down to secure it.

Print this surface down

2-28 screw inserted through the main PCB threads in here.

### LCD Clamp

Provides additional support to the long side of the LCD modules. Two of these need to be printed.


A 4-20 thread rolling screw inserts through the LCD Clamp into threads into the hole indicated. The clamp is oriented so that the recessed part is down facing the LCD.

Print this face up

4-20 screw inserted through the LCD Clamp threads in here.


### Buzzer Clamp

Provides additional support for the piezo buzzer.

Print this face up

Presses against backside of piezo buzzer (which is inserted into a slot at the bottom of the Main Enclosure Base). The Buzzer Clamp attaches to the Main Enclosure Base via two 2-28 thread rolling screws threaded into mounting points on the left side of the enclosure as shown below.

2-28 screws thread into
the two indicated holes


### AltIMU Bracket

Secures the AltIMU module to the PCB.


This part does not directly attach to any other 3D part but instead attaches between AltIMU module and holes in the main PCB. Two 2-28 thread-rolling screws are inserted through the AltIMU module and two through the main PCB and are threaded into the AltIMU Bracket’s top and bottom holes, respectively.

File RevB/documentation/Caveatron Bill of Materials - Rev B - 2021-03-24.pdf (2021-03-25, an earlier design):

## Caveatron Bill of Materials

### Hardware Revision: B Date: 2021-03-24

All the parts in this list have been tested with the Caveatron and integrated into the code. For some parts, alternate options are available.
Item | Qty | Manufacturer | Mfr. P/N | Description | Suggested Vendor Link | Photo
Main Processor | 1 | PJRC Electronics | Teensy 3.6 | Teensy 3.6 | PJRC Store (https://www.pjrc.com/store/teensy36_pins.html) Amazon (https://www.amazon.com/PJRC-Teensy-3-6-with-pins/dp/B01MG2PYYP)


Notes: The main system processor. Available from multiple vendors. Versions with and without the pins pre-installed are available (link above is with pins).

Touchscreen
LCD

OPTION 1

1 | BuyDisplay | N/A | LCD 3.5” 320x480 TFT Display Module, OPTL Touch Screen w/Breakout Board
| | | Options: -Resistive touch panel -16-bit 8080 40-pin header -3.3V supply -No font chip

BuyDisplay (https://www.buydisplay.com/lcd-3-5-inch-320x480-tft-display-module-optl-touch-screen-w-breakout-board)


Notes: The display and user interface. This is the new and currently preferred display option. A revised enclosure lid design is available for this display.

Item | Qty | Manufacturer | Mfr. P/N | Description | Suggested Vendor Link | Photo
Touchscreen LCD OPTION 2 | 1 | Coldtears Electronics | N/A | 3.5 inch TFT LCD module w/Font IC 480x320 full angle Arduino DUE MEGA 3.2 4.3 | No longer available


Notes: Alternate display. This display was previously the preferred choice but is likely no longer going to be availabe. At present the Caveatron enclosure is only designed to use this display.
Touchscreen
LCD

OPTION 3

1 Coldtears
Electronics

N/A 4.0" inch TFT LCD module w/Font IC 480x320 ILI
arduino DUE MEGA 3.2 2.5
STM32

No longer
available


Notes: Alternate display. Same resolution as the 3.5” in a larger size but with slightly less viewing angle contrast. This display is likely no longer going to be available. Graphics
Module (SPI
Flash
Memory)

1 Multiple (Winbond IC)

W25Q64
or similar

W25Q64 64Mbit 8MByte
Flash Memory Module
Data Flash SPI Interface

Amazon (https://www.amazon.com/NOYITO-W25Q64-64Mbit-DataFlash-Interface/dp/B07C4JN857)


Notes: Storage for fonts and graphics used in the GUI. SPI Flash memory must be Winbond W25Q32, W25Q64, or W25Q128 (memory size should be 32Mbit or higher.) Winbond W25Q16 (16 Mbit) could be used, but will only hold the fonts and not support the graphics.

Item | Qty | Manufacturer | Mfr. P/N | Description | Suggested Vendor Link | Photo
Laser Rangefinder OPTION 1 | 1 | Uni-T | UT390B | Laser Distance Meter | Availability very limited. Internet searches will still occasionally find one.

Notes: Used for station distance measurements. This item is long since discontinued but can still be found online from a few sources. Do not confuse this with the UT390B+, which is widely available but does not have an accessible serial port, so is not useable. The UT390B+ has a bubble level in the upper left which the UT390B does not. The UT390B must be disassembled and the LCD removed to access the electronics board. The JRT rangefinder (OPTION 2) has wider availability, but has operational disadvantages. The UT390B remains the preferred rangefinder if you can find one.
Laser
Rangefinder

OPTION 2

1 JRT Meter
Tech., Co, Ltd.

Unknown 100m Laser Distance Sensor Module

Ebay (https://www.ebay.com/itm/laser-distance-meter-serial-module-TTL-RS232-laser-meter-sensor/292329869069)
Availability changes
frequently. Site
linked above has
availability as of the
date of this BOM

Notes: Used for station distance measurements. This rangefinder module is similar in size to Option 1 above and is easier to find. However, it’s method of operation is less well suited to the Caveatron since it has a variable measurement time (rather than the UT390B’s fixed 1 sec measurement time) and can take up to 3 sec to acquire a reading or timeout. This means that when scanning in Passage mode, you can end up with fewer reference points and a less accurate scan.

Item | Qty | Manufacturer | Mfr. P/N | Description | Suggested Vendor Link | Photo
Laser Rangefinder OPTION 3 | 1 | JRT Meter Tech., Co, Ltd. | Unknown | 40m – 60m Laser Distance Sensor Module | Ebay (https://www.ebay.com/itm/DIY-Laser-Distance-Meter-RS232-TTL-Serial-Module-Range-Finder-Sensor/292750515920) Availability changes frequently. Site linked above has availability as of the date of this BOM

Notes: Used for station distance measurements. This rangefinder module has not been tested but it appears to operate with an identical protocol to the Option 2 rangefinder, so would be compatible. However, it also likely has the same performance considerations. It is significantly smaller than the others.
IMU/
Compass
Module

OPTION 1

1 | Pololu | MinIMU-9 v5 (#2738)
| | Or
| | AltIMU-10 v5 (#2739)

AltIMU-10 v5 Gyro,
Accelerometer, Compass,
and Altimeter (L3GD20H,
LSM303D, and LPS331AP
Carrier)

Pololu (https://www.pololu.com/product/2738)

Notes: Used to determine orientation of the Caveatron and measure azimuth and inclination. This is the best currently available IMU module option although the discontinued models below have half the noise floor if you can find them. The AltIMU-10 and MinIMU are equivalent parts since the altitude sensor in the AltIMU is not used.
IMU/
Compass
Module

OPTION 2

1 | Pololu | AltIMU-10 v3 (#2469)
| | Or
| | AltIMU-10 v4 (#2470)

AltIMU-10 v3 Gyro,
Accelerometer, Compass,
and Altimeter (L3GD20H,
LSM303D, and LPS331AP
Carrier)

Pololu (https://www.pololu.com/product/2469)
(Discontinued)

Notes: Used to determine orientation of the Caveatron and measure azimuth and inclination. The AltIMU-10 v4 is an equivalent part and can also be used. The older v3 and v4 versions of the modules are preferred over the newest AltIMU-10 v5 or the MinIMU-9 v5 since the magnetometer in this module (LSM303D) has a lower noise output than the LIS3MDL used in the newest versions. At this time, it appears that this part is no longer available.
Compass
Module

OPTION 3

1 | Pololu | LSM303D (#2127)

LSM303D 3D Compass and
Accelerometer Carrier
with Voltage Regulator

Pololu (https://www.pololu.com/product/2127)
(Discontinued)

Notes: Used to measure azimuth and inclination. As an alternative to the single AltIMU, separate compass and gyroscope modules are supported, but must be co-aligned with each other. This module uses the same accelerometer and magnetometer IC as the AltIMU-10 v3 and v4. If you use this option, you must also option the gyroscope module below. At this time, it appears this part is no longer available.
Gyroscope
Module

OPTION 3

1 | Pololu | L3GD20H (#2129)
| | Or
| | L3GD20 (#2125)

L3GD20H 3-Axis Gyro
Carrier with Voltage
Regulator

Pololu (https://www.pololu.com/product/2129)
(No longer
needed since
LSM303D is
discontinued)

Notes: Used to supplement compass module to improve orientation measurement. This part is used ONLY if the separate OPTION 3 LSM303D compass module above is used rather than the integrated MinIMU or AltIMU. It must be aligned to the LSM303D. The older L3GD20 module can also be used.

Item | Qty | Manufacturer | Mfr. P/N | Description | Suggested Vendor Link

Photo
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

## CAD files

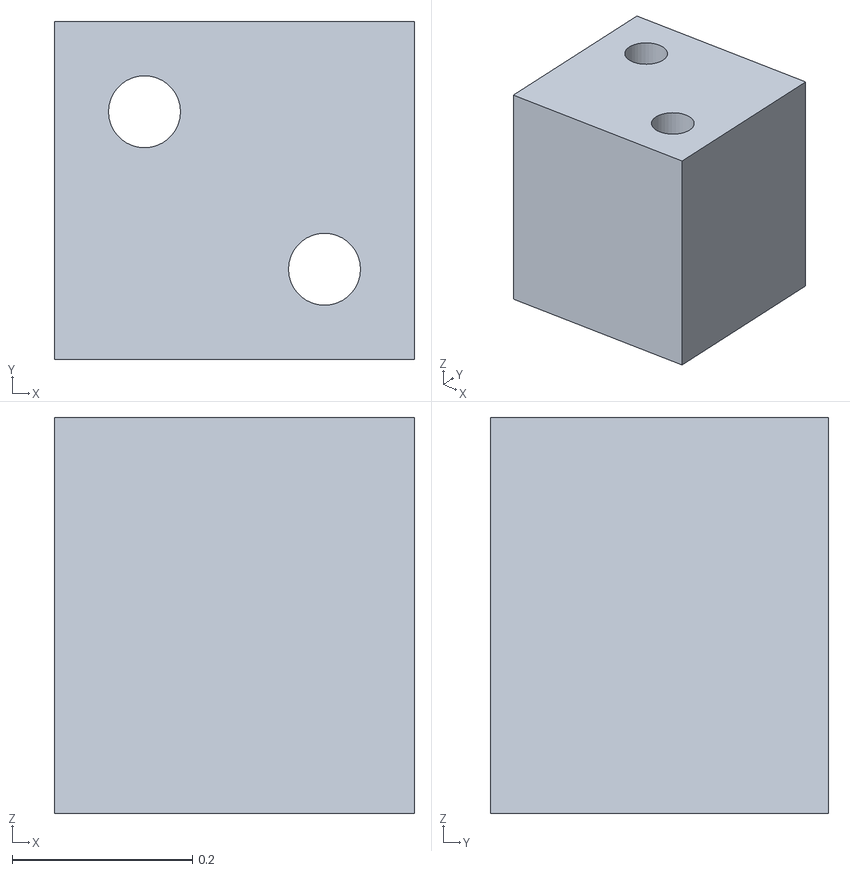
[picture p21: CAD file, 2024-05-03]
RevC/mechanical/LSM6DS33 Bracket for 8.5mm headers v2.stl
0.4 x 0.375 x 0.44

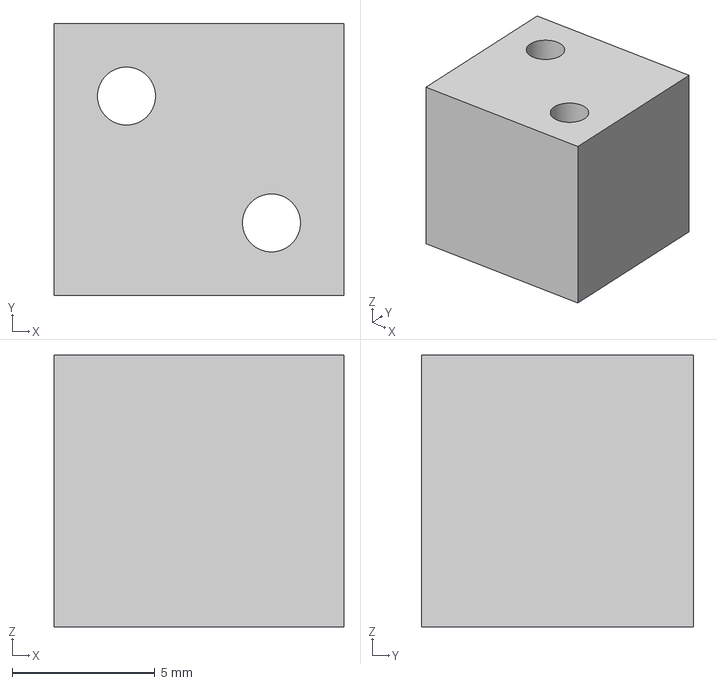
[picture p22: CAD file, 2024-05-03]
RevC/mechanical/STEP files/LSM6DS33 Bracket for 7mm headers v2.step
10.2 x 9.52 x 9.52 mm

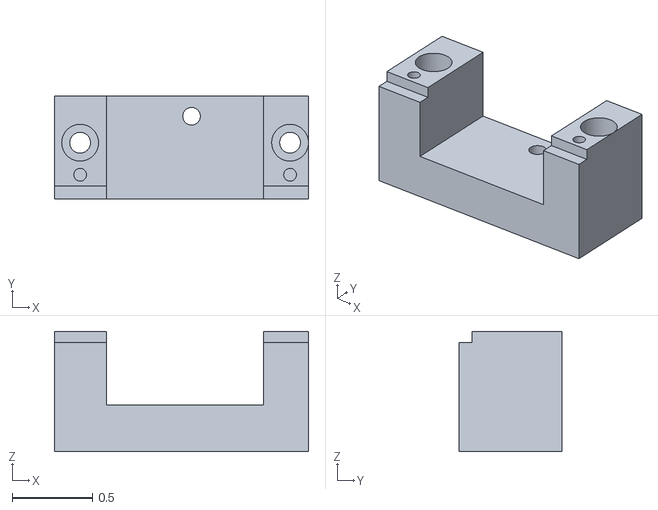
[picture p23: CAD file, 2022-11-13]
RevC/mechanical/LRF Bracket v1.stl
1.59 x 0.64 x 0.75

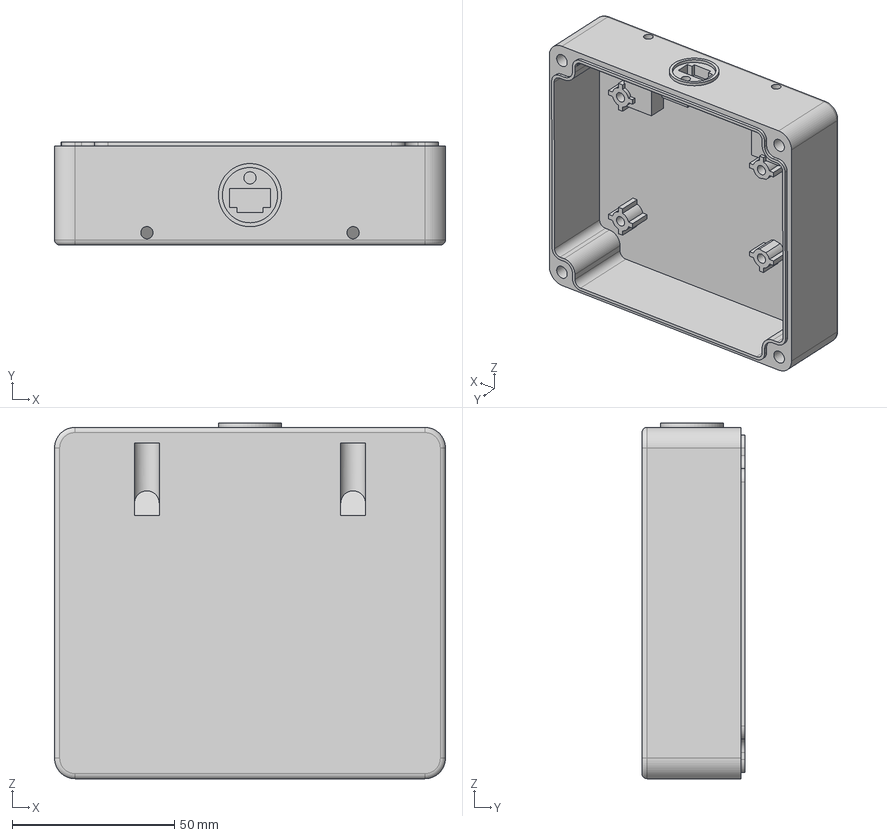
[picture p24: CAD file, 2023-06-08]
RevC/mechanical/STEP files/RPLIDAR A1 Enclosure Base v3.step
120.4 x 31.8 x 109.5 mm

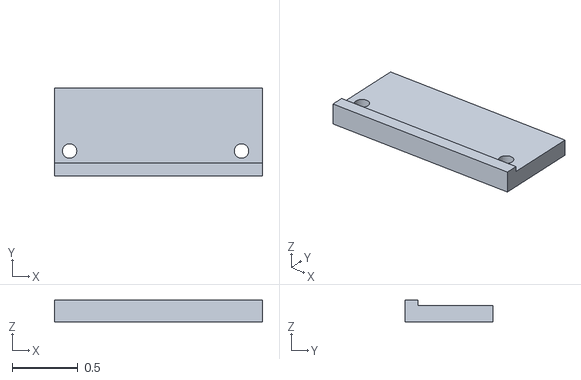
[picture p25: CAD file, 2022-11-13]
RevC/mechanical/LRF Clamp v3.stl
1.59 x 0.67 x 0.165

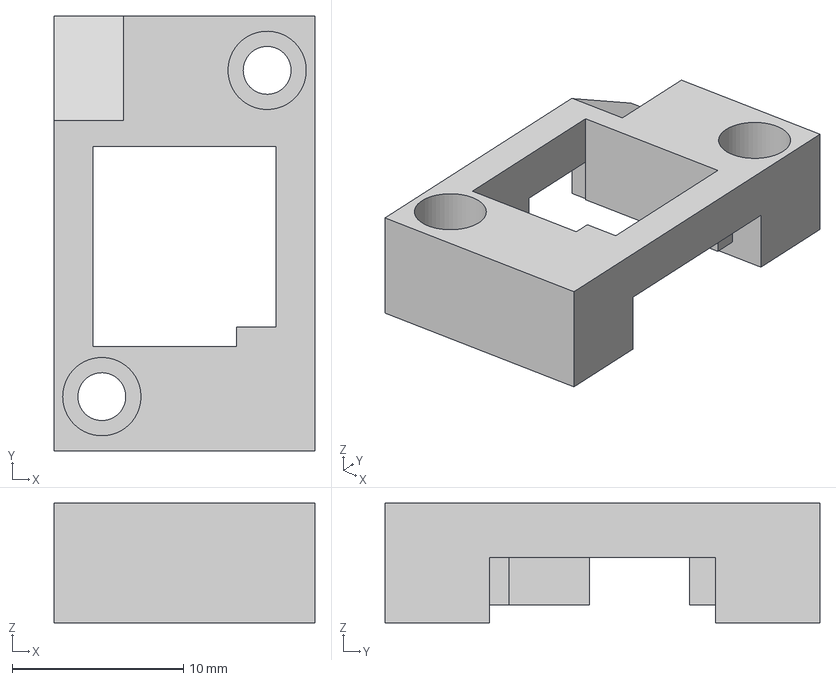
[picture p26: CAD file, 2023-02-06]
RevC/mechanical/STEP files/RM3100 Clamp v3.step
15.2 x 25.4 x 6.98 mm

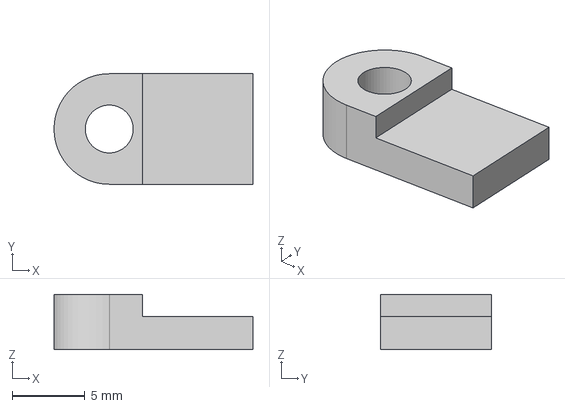
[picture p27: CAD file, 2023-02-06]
RevC/mechanical/STEP files/LCD Clamp v2.step
13.7 x 7.62 x 3.81 mm

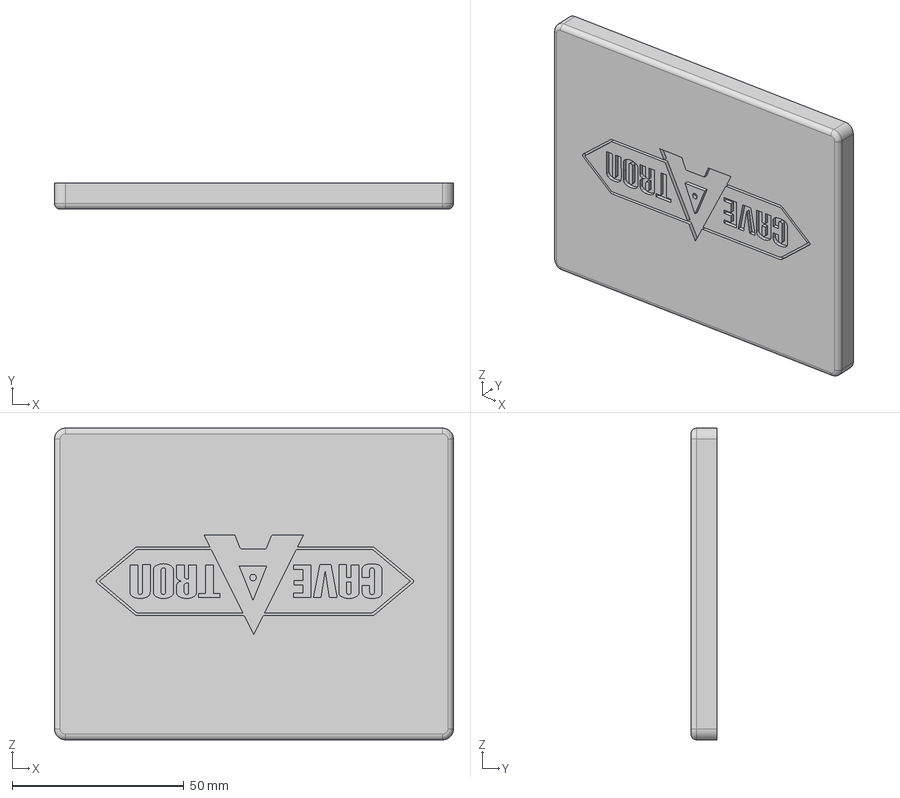
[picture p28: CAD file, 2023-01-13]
RevC/mechanical/STEP files/RPLIDAR A1 Enclosure Lid (Top) v5.step
116.1 x 7.62 x 90.7 mm

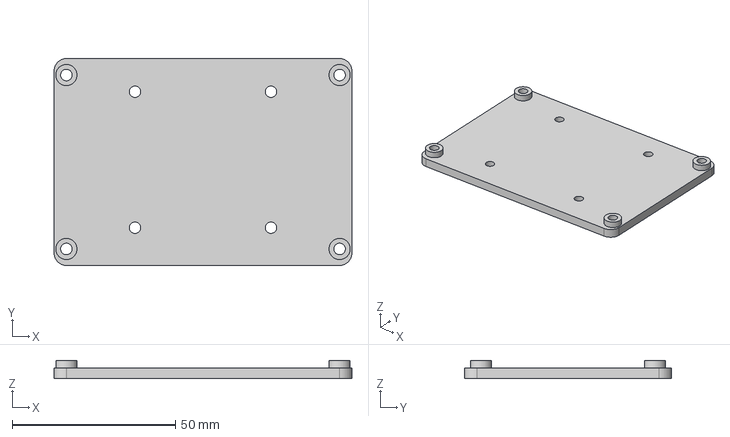
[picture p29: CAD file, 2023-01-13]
RevC/mechanical/STEP files/RPLIDAR S2 Mounting Plate v8.step
91.4 x 63.5 x 5.60 mm

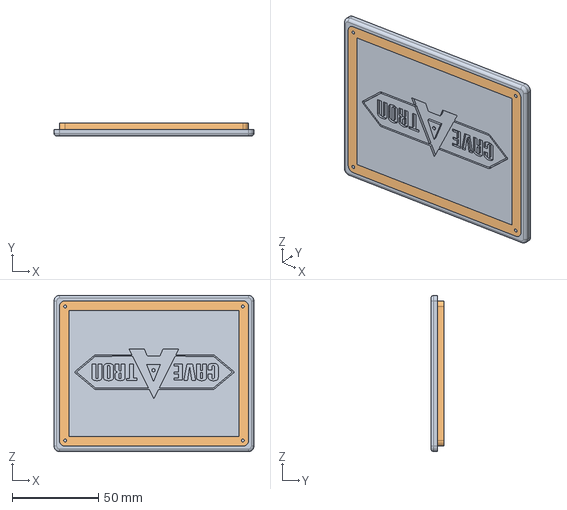
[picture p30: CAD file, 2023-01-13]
RevC/mechanical/STEP files/RPLIDAR A1 Enclosure Lid - No Windows (Top) v3.step
116.1 x 7.62 x 90.7 mm

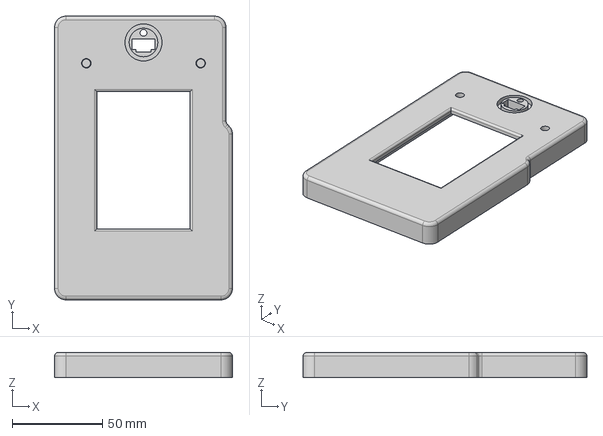
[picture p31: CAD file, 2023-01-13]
RevC/mechanical/STEP files/Caveatron Rev C Lid v6.step
98.8 x 157.5 x 14.0 mm

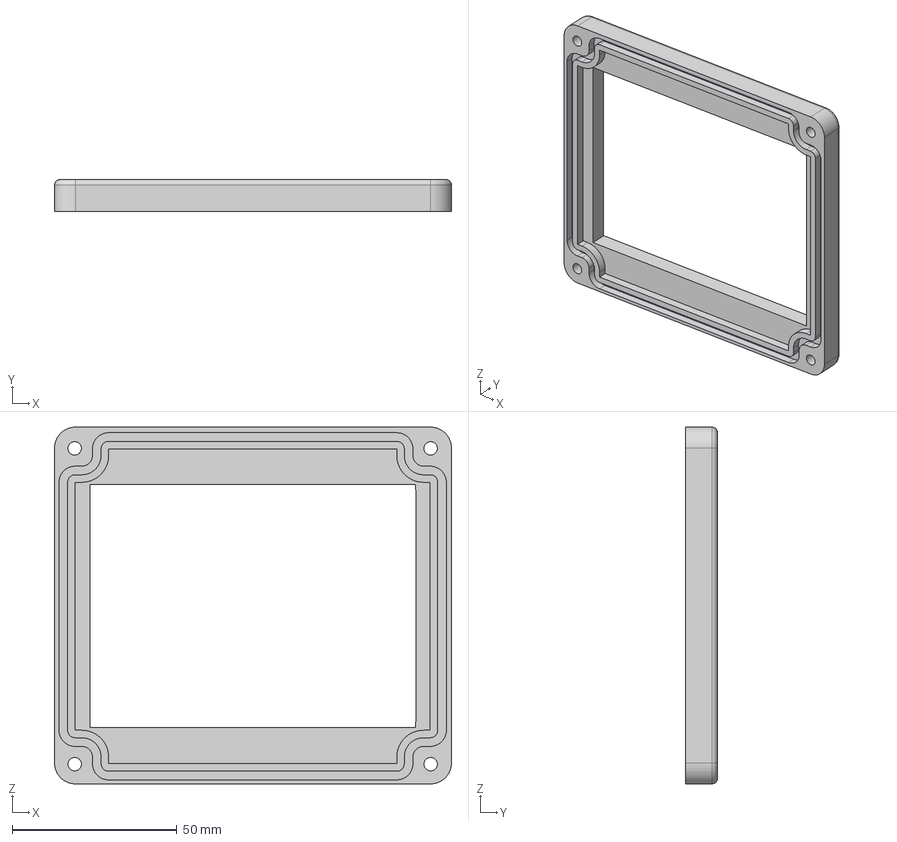
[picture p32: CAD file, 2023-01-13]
RevC/mechanical/STEP files/RPLIDAR A1 Enclosure Lid (Bottom) v4.step
120.4 x 9.65 x 108.2 mm

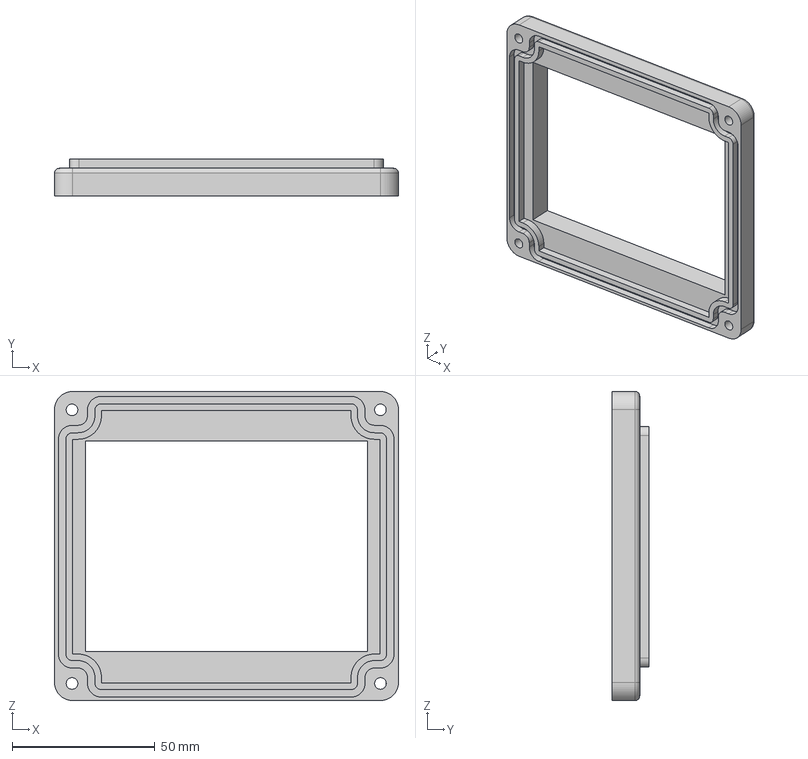
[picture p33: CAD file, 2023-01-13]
RevC/mechanical/STEP files/RPLIDAR A1 Enclosure Lid - No Windows (Bottom) v4.step
120.4 x 12.8 x 108.2 mm

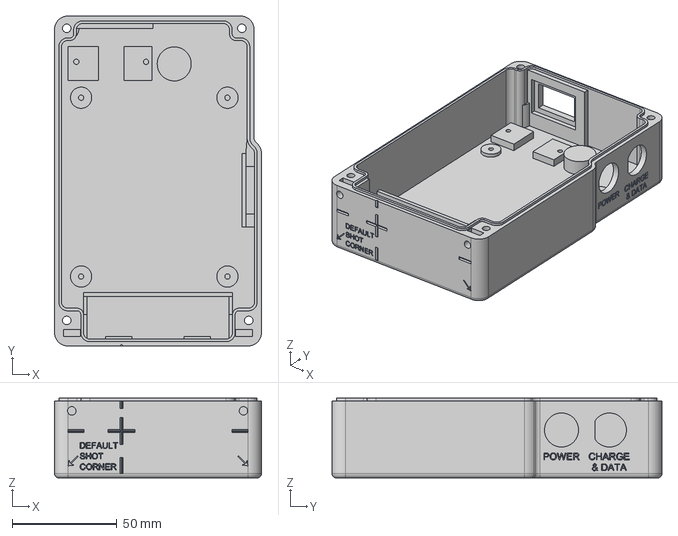
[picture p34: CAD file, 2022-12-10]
RevC/mechanical/STEP files/Caveatron Rev C Base v16.step
98.8 x 157.5 x 38.1 mm

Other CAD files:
RevC/mechanical/STEP files/LRF Bracket v3.step
RevC/mechanical/STEP files/RPLIDAR S2 Rev C Base v7.step
RevC/mechanical/STEP files/MinIMU Bracket v1.step
RevC/mechanical/STEP files/LRF Cradle v1.step
RevB/mechanical/AltIMU Bracket v1.stl
RevB/mechanical/Battery Charging Board Support Post v2.stl
RevB/mechanical/Buzzer Clamp v7.stl
RevB/mechanical/Caveatron Main Enclosure Base v32.stl
RevB/mechanical/Caveatron Main Enclosure Lid - BuyDisplay v2.stl
RevB/mechanical/Caveatron Main Enclosure Lid v16.stl
RevB/mechanical/Fusion360 Versions/AltIMU Bracket v1.f3d
RevB/mechanical/Fusion360 Versions/Board support post v2.f3d
RevB/mechanical/Fusion360 Versions/Buzzer Clamp v7.f3d
RevB/mechanical/Fusion360 Versions/Caveatron Main Enclosure Base v32.f3d
RevB/mechanical/Fusion360 Versions/Caveatron Main Enclosure Lid - BuyDisplay v2.f3d
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

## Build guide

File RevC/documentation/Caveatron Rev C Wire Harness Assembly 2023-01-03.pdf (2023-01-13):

## Caveatron Rev C - Wire Harness Assembly

Version: 2023-01-03

CAUTION: Do not pay attention to wire colors except where noted below. Pre-wired connectors are usually wired with arbitrary wire colors so will not be consistent. Be especially careful with two wire connectors to be sure you are not wiring it backwards (sometimes the black wire on these pre-wired connectors is in the positive position!)

### Connectors, Pin Conventions, and General Notes

These connectors are used in the wire harnesses and the pin number convention is shown below:
- JST XH 2.54 5-pin connectors are used on the Laser Rangefinder (LRF) and the Power Switch.
- JST XH 2.54 2-pin connectors are used for USB Power/Data and the Piezo Buzzer.
- For RPLIDAR A1M8 Only: JST GH 1.25 4-pin connector is used on the LIDAR main PCB connector.
- For RPLIDAR A1M8 Only: JST GH 1.25 3-pin connector is used on the LIDAR main motor connector.
JST XH (2.54 mm) | JST Micro GH (1.25 mm)

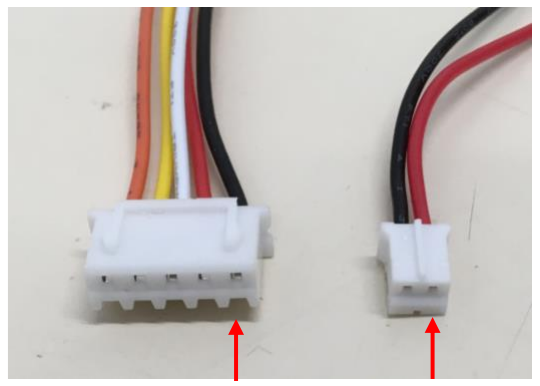
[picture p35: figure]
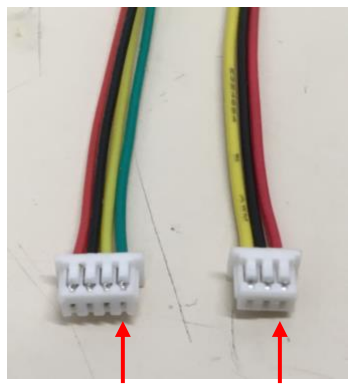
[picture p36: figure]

Pin 1 | Pin 1 | Pin 1 | Pin 1

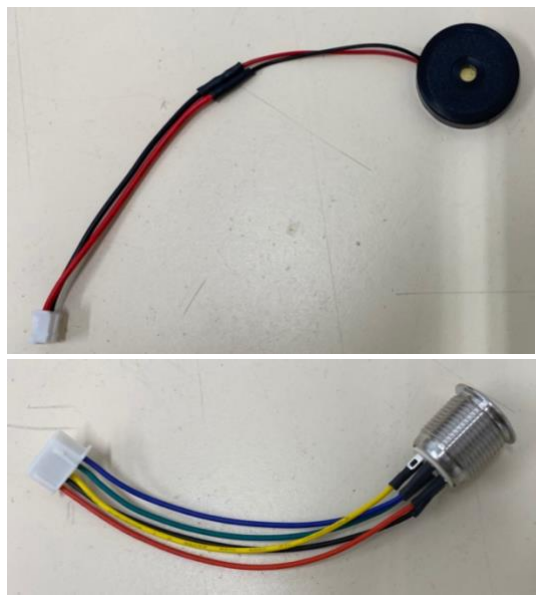
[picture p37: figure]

The photos at left shows examples of two of the wiring harnesses used in the Caveatron (others are shown on subsequent pages). It is highly recommended that heat shrink tubing be used on all solder interfaces and as strain relief on soldered pins. Kapton tape and/or small cable ties can be used for additional strain relief. Be extra careful when wiring the battery to avoid allowing the wires to touch.

Used for
RPLIDAR A1M8
only. All other
LIDARs use their
included cable.

### Laser Rangefinder

Pin on PCB Connector | Description
1 | +3.0 V
2 | GND
3 | RX on Teensy / TX on LRF
4 | TX on Teensy / RX on LRF
5 | -

Length of Wire Harness: 5”

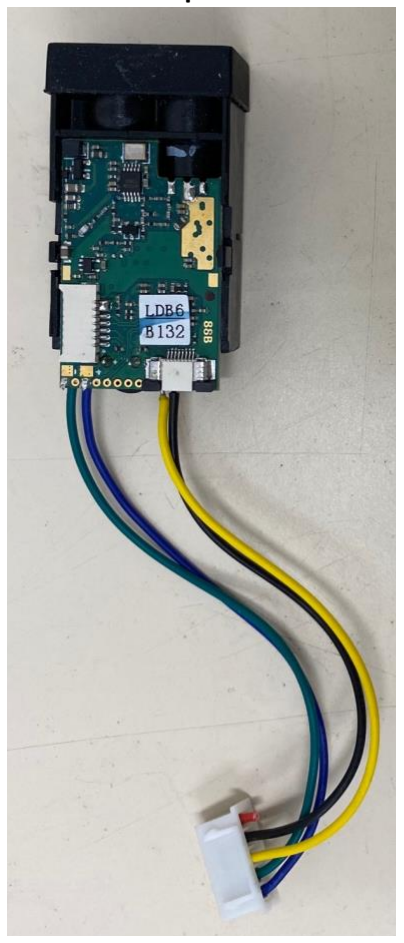
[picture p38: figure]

### Power Switch

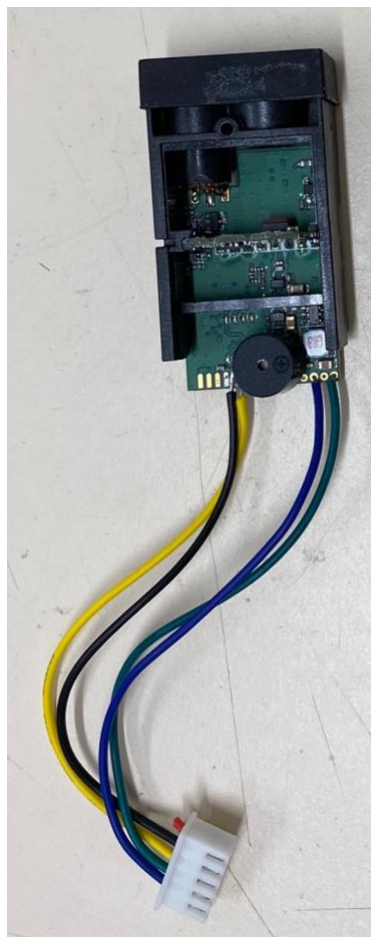
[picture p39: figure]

Pin on PCB Connector | Description
1 | +5 V (C+)
2 | Red LED Cathode
3 | Green LED Cathode
4 | Switch A
5 | Switch B
(Switch A and B do not have a polarity and can be reversed)
Top View | Bottom View

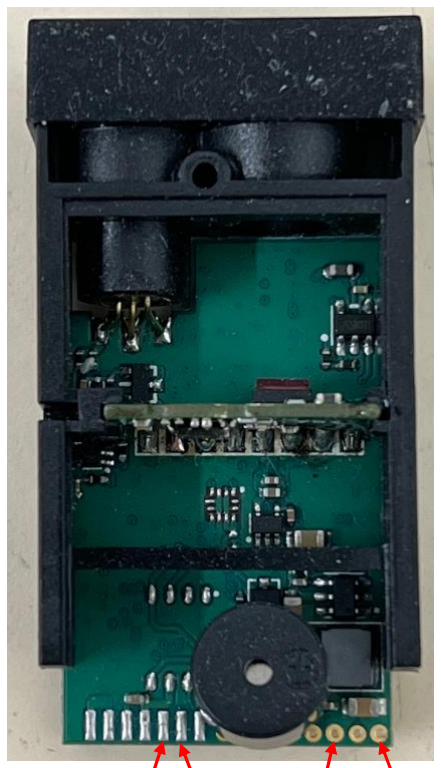
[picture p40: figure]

V+
GND TX on LRF
(RX on Teensy) RX on LRF (TX on Teensy)

Length of Wire Harness: 3.5”

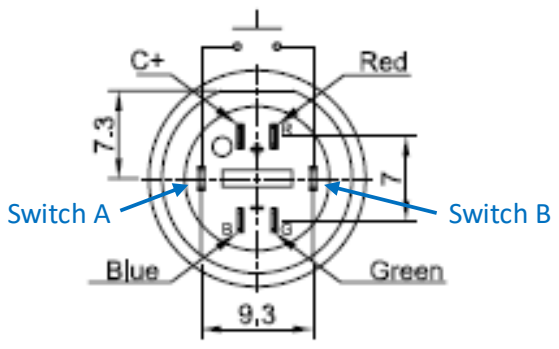
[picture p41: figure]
Switch A; Switch B

### Piezo Buzzer

Pin on PCB Connector | Description | Piezo Buzzer Wire Color
1 | +V | Red
2 | GND | Black

Length of Wire Harness: 5”

### USB Power/Data Connector

This Y-cable goes from the USB mini/micro external jack to a 2 pin JST and to a USB micro male connector.

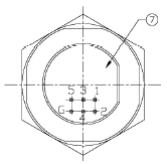
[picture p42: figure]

Pin on USB Connector | Description | Pin on micro-USB Power Connector | Pin on 2-wire USB Data Connector
1 | +5 V (VCC) | 1
2 | D- | | 2
3 | D+ | | 1
4 | -
5 | GND | 2
G | GND | 2

Length of each leg of wire harness (not including USB Micro): 2.5”

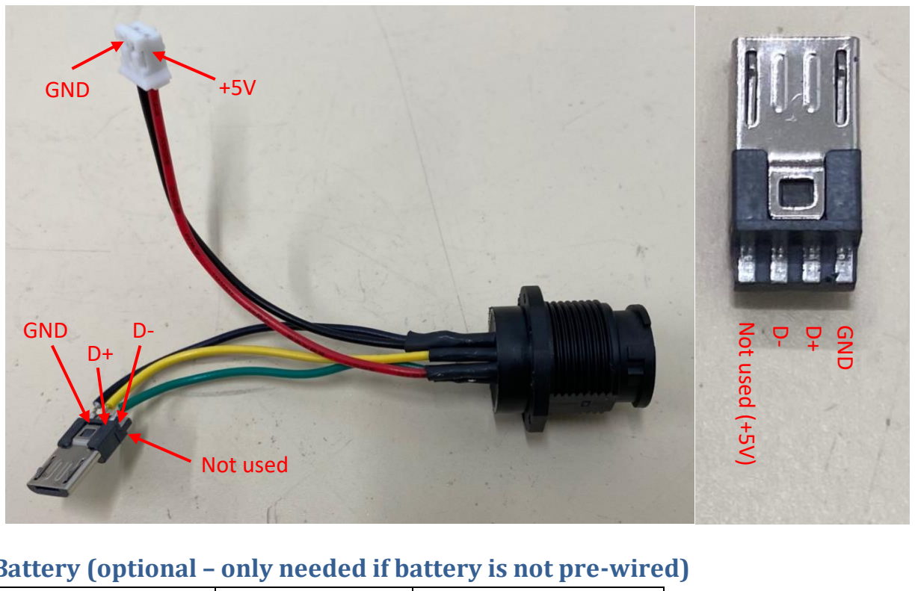
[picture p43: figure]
GND; Not used; Not used (+5V)

### Battery (optional – only needed if battery is not pre-wired)

Pin on PCB Connector | Description | Battery Wire Color
1 | +V | Red
2 | GND | Black

Length of Wire Harness: 2.75”

### LIDAR (optional – only needed with the RPLIDAR A1M8)

For other supported RPLIDAR modules, the LIDAR’s built-in connector is plugged directly into the Caveatron PCB Connector.

Pin on PCB Connector | Description | 4-Pin Connector on RPLIDAR A1M8 | 3-Pin Connector on RPLIDAR A1M8
1 | +5 V (VCC_5, VMOTO) | 2 | 1
2 | TX on LIDAR / RX on Teensy | 4 | -
3 | RX on LIDAR / TX on Teensy | 3 | -
4 | GND | 1 | 3
5 | PWM Motor Controller (MOTOCTL) | - | 2

Length of Wire Harness: 7.5”

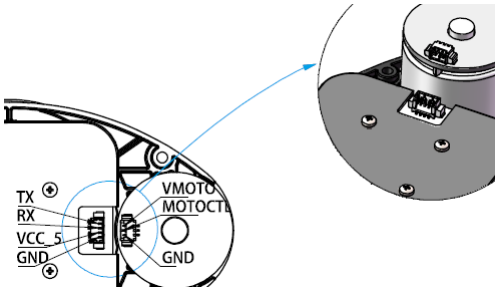
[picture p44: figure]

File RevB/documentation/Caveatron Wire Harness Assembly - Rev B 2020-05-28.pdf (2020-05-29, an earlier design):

## Caveatron Rev B - Wire Harness Assembly

Version: 2020-05-28

CAUTION: Do not pay attention to wire colors except where noted below. Pre-wired connectors are usually wired with arbitrary wire colors so will not be consistent. Be especially careful with two wire connectors to be sure you are not wiring it backwards (sometimes the black wire on these pre-wired connectors is in the positive position!)

### Connectors, Pin Conventions, and General Notes

These connectors are used in the wire harnesses and the pin number convention is shown below:
- JST XH 2.54 5-pin connectors are used on the Laser Rangefinder, the LIDAR, and the Power Switch.
- JST XH 2.54 2-pin connectors are used on the Piezo Buzzer and the Battery.
- JST GH 1.25 4-pin connector is used on the LIDAR main PCB connector.
- JST GH 1.25 3-pin connector is used on the LIDAR main motor connector.
JST XH (2.54 mm) | JST Micro GH (1.25 mm)

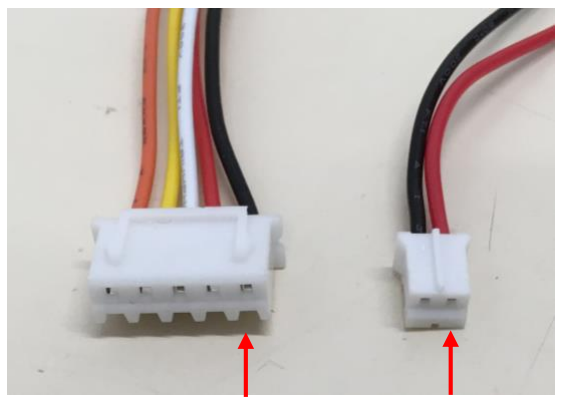
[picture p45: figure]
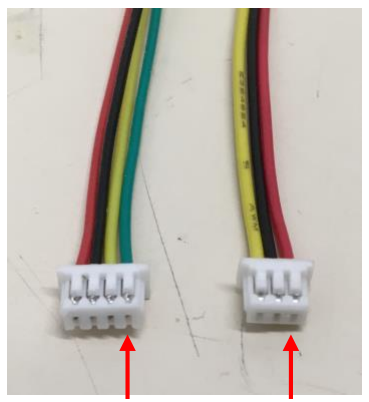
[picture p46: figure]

Pin 1 | Pin 1 | Pin 1 | Pin 1

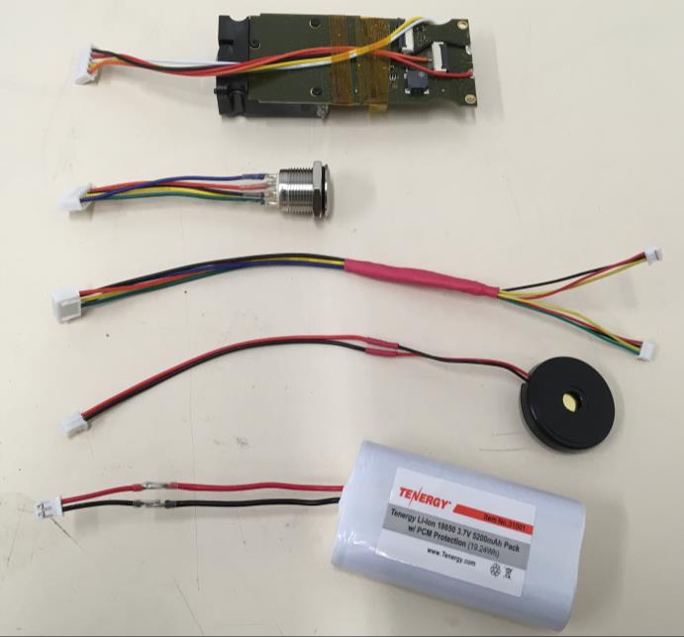
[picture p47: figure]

The photo at left shows examples of the wiring harnesses used in the Caveatron. It is highly recommended that heat shrink tubing be used on all solder interfaces and as strain relief on soldered pins and cable splits where appropriate. Kapton tape is used for additional strain relief on the LRF. Be extra careful when wiring the battery to avoid allowing the wires to touch.

### Laser Rangefinder

Pin on PCB Connector | Description
1 | +3 V
2 | GND
3 | RX on Teensy / TX on LRF
4 | TX on Teensy / RX on LRF
5 | Power On (used on UT390B only)

Length of Wire Harness (for UT390B): 7.5” for V+/GND, 7.75” for RX/TX, 7” for Power On.

### UT390B

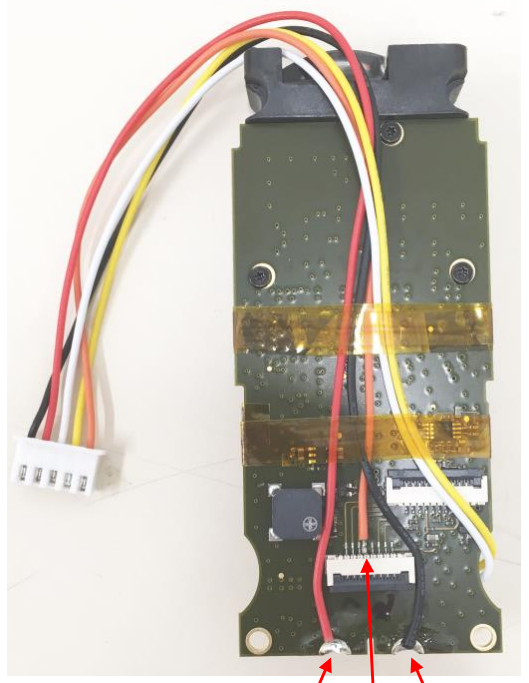
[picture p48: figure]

### JRT 100m LIDAR Module (Large)

GND | V+
Power On

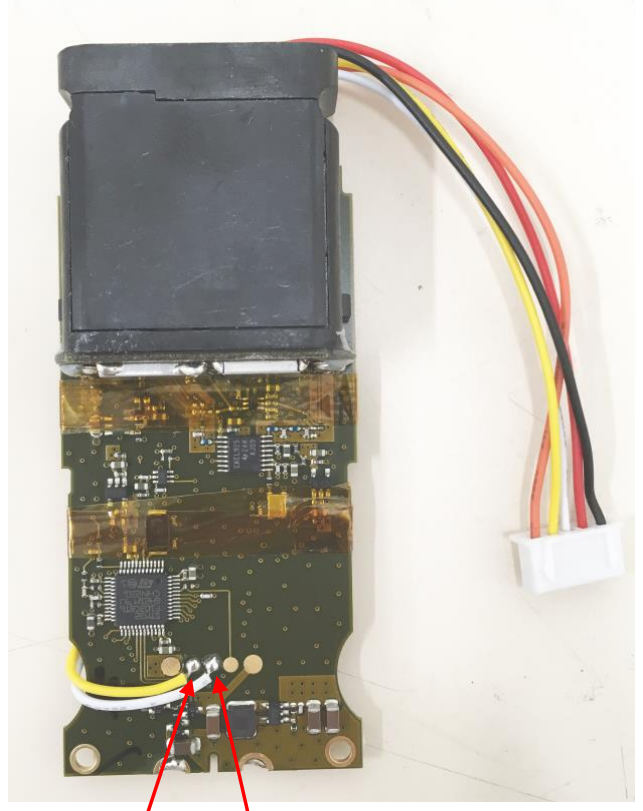
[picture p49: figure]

RX on LRF
(TX on Teensy)

TX on LRF
(RX on Teensy)
Top View | Bottom View

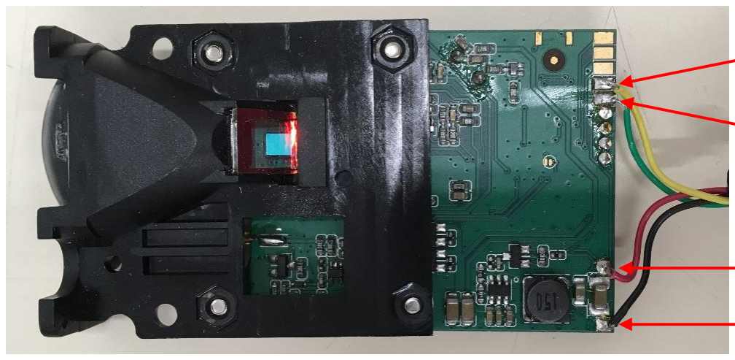
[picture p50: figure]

V+

GND

TX on LRF
(RX on Teensy)

RX on LRF
(TX on Teensy)

### JRT 40m LIDAR Module (Small)

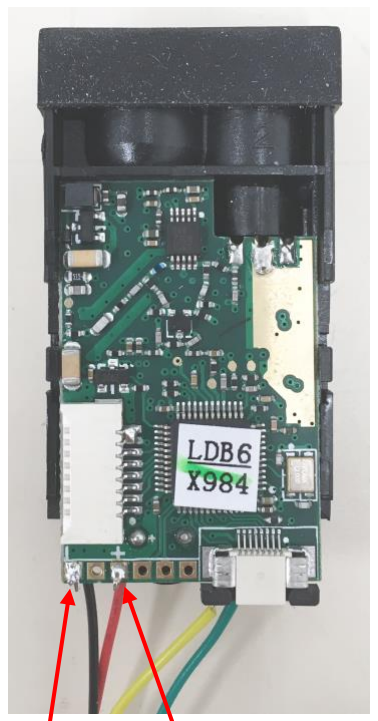
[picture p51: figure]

### LIDAR

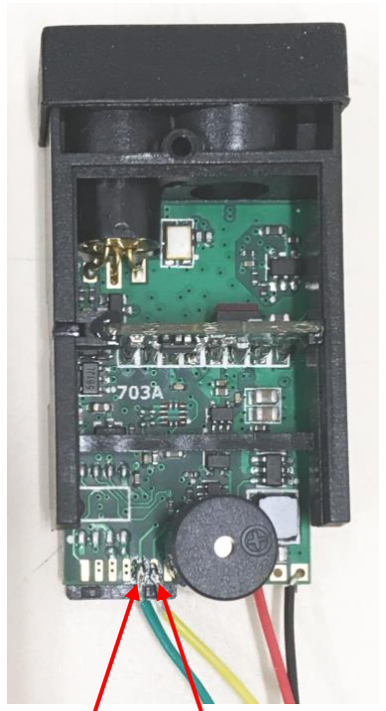
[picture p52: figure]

Pin on PCB Connector | Description | 4-Pin Connector on RPLIDAR | 3-Pin Connector on RPLIDAR
1 | +5 V (VCC_5, VMOTO) | 2 | 1
2 | GND | 1 | 3
3 | RX on Teensy / TX on LIDAR | 4 | -
4 | TX on Teensy / RX on LIDAR | 3 | -
5 | PWM Motor Controller (MOTOCTL) | - | 2

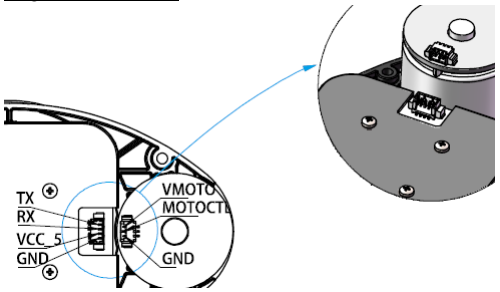
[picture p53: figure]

Length of Wire Harness: 7.5”

GND | V+ | TX on LRF (RX on Teensy)
RX on LRF
(TX on Teensy)
Top View | Bottom View

### Power Switch

Pin on PCB Connector | Description
1 | +5 V (C+)
2 | Red LED Cathode
3 | Green LED Cathode
4 | Switch A
5 | Switch B
(Switch A and B do not have a polarity and can be reversed)

Length of Wire Harness: 2.5”

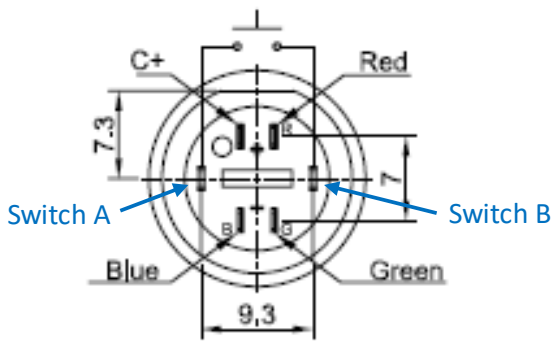
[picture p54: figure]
Switch A; Switch B

### Piezo Buzzer

Pin on PCB Connector | Description | Piezo Buzzer Wire Color
1 | +V | Red
2 | GND | Black

Length of Wire Harness: 6.5”

### Battery

Pin on PCB Connector | Description | Battery Wire Color
1 | +V | Red
2 | GND | Black

Length of Wire Harness: 2.75”

### USB Connector

(Only needed if you use the solder terminal version of the connector)
Pin on USB Connector | Description
1 | +5 V (VCC)
2 | D-
3 | D+
4 | -
5 | GND
G | GND

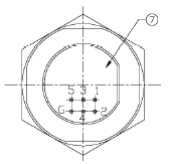
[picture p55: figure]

Length of Wire Harness (including USB Micro): 4.25”

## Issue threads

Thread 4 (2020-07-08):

Can’t find the screens anymore

pupshadow, 2020-07-08:
You can’t find this screen style anymore is there a way you could probably use this one? https://www.ebay.com/itm/174237082264

It’s a 3.2 one but and has every single pin out the same.

TomSouthCoast, 2020-08-23:
Same problem. Anyone able to help?

fishking2, 2020-08-25:
Gotta feel for Joe, this isn't an easy project to stay on top of sourcing all the parts.  Can't expect him to keep it perfectly up to date for us.

Since the ebay listing is now a dead link instead of just sold out, I figured I'd drop some of the info about the part.
Original listing title: 3.5" inch TFT LCD module w/Font IC 480x320 full angle arduino DUE MEGA 3.2 4.3
Seller: coldtears.electronics
Last seen in stock late April 2020
[Original Link](http://www.ebay.com/itm/3-5-inch-TFT-LCD-module-w-Font-IC-480x320-full-angle-arduino-DUE-MEGA-3-2-4-3-/121057702584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)

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

@pupshadow Your ebay link is pretty close.  There's other 3.5" touch tft lcd modules with similar 40 pin layouts and even similar IC drivers that can be found on aliexpress, but the pinout has been different as far as I can tell.  Some adjustments on your PCB might be able to account for this, but honestly I have no clue how similar the hardware would actually end up being.
[Aliexpress example](https://www.aliexpress.com/item/4000223346554.html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,searchweb201602_,searchweb201603_)

Think that the original screen may have also been model #CTE35IPS and was supposed to function using the UTFT_GHL library.  Good luck on your search.

paulwalko, 2020-08-26:
The original ebay link is down but the item description link from the ebay link is not (thanks to archive.org!): http://vi.vipr.ebaydesc.com/ws/eBayISAPI.dll?ViewItemDescV4&item=121057702584

TomSouthCoast, 2020-08-27:
Thanks both, that’s useful.

 Joe has done an incredible job with this and with producing the guides that even electronics novices like myself can follow.

I was just wondering if anyone had found a solution to this issue the other more readily available hardware. From what I understand, there are compatibility issues even if you can find a touchscreen with the same pin layout?

paulwalko, 2020-08-27:
There's a pretty good discussion on the mailing list about it from June: https://groups.google.com/g/caveatron-discuss/c/gQr5aQqxIDQ

From what I can tell the key components that have to be the same are the pinout, driver IC, and resolution, among other smaller things I'm sure. Seems like anything other than the exact LCDs listed in the BOM require some type of modification to the PCB and/or the firmware.

TomSouthCoast, 2020-08-28:
Thanks for the information. I did wonder whether this coldtears device uses the same screen. https://www.ebay.com/itm/LCDsysinfo-for-GOverlay-v2-0-USB-3-5-TFT-LCD-Module-gamer-gadget-external/121267744346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 It doesn’t state that it is touchscreen but I’ve emailed the seller to find out!

Regards Tom

On 27 Aug 2020, at 17:46, Paul Walko <notifications@github.com> wrote:

There's a pretty good discussion on the mailing list about it from June: https://groups.google.com/g/caveatron-discuss/c/gQr5aQqxIDQ<https://eur03.safelinks.protection.outlook.com/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>

From what I can tell the key components that have to be the same are the pinout, driver IC, and resolution, among other smaller things I'm sure. Seems like anything other than the exact LCDs listed in the BOM require some type of modification to the PCB and/or the firmware.

—
You are receiving this because you commented.
Reply to this email directly, view it on GitHub<https://eur03.safelinks.protection.outlook.com/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>, or unsubscribe<https://eur03.safelinks.protection.outlook.com/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>.

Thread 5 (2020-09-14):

Usage overview

xairy, 2020-09-14:
Hi,

I've stumbled upon this awesome project and I've been trying to figure out how difficult it is to use it.

What's the overall usage process for this device? I see that the website mentions using a "small station marker card". Does one use this station to scan the surroundings and then moves the station somewhere else? Does the position of the station needs to be somehow recorded somewhere? How long does it take to scan a tunnel of a particular length?

All this information would be quite useful to be included into the README.

Thanks in advance!

xairy, 2020-09-14:
Actually, looks like [this page](http://caveatron.com/description.html) answers some of these questions.

However it's still unclear, whether one needs to know and record the positions of the survey stations?

And what does one use as a survey station "retroreflective card"?

xairy, 2020-09-14:
Ah, I see the stations parts listed in the bill of materials :)

OK, so one just needs to set up these station throughout the cave and then walk through them in sequence while holding the device? Seems easy enough.

koloshiol, 2020-09-15:
Andrey,
Generally you'll do a survey with 2-3 person teams. Doesn't matter what
equipment you have, it generally happens in the same way.

-One person in front looking for the next station. Verify line of sight
with the 2nd person a with a flashlight or laser pointer. Usually we mark
the station with whiteout, and every few get the station number added so
you don't lose track of where you're at. This person would hold a few
retroreflective cards in a pocket, and hold them still when told.

-2nd person has the device (compass/inclinometer, disto, or caveatron).
They help verify line of sight with person 1, then use the device to
measure the shot to the next station where #1 is.

-3rd person is your sketcher (not really needed with a LIDAR present). They
would normally hear #2 calling out distance, inclination/declination,
azimuth, and LRUDs and write them down. They also draw cross sections as
needed. Periodically they will add the passages to a bird's eye map on
paper.

Scanning a passage between two stations can take as little or as much time
as you like. The LIDAR spins at a certain RPM and takes measurements at a
certain frequency. So you'll end up with distances in a corkscrew pattern
that's dependent on time, not distance. If you travel faster the corkscrew
essentially gets stretched like a spring and you have fewer measurements
per linear distance traveled. Go slower, and the pattern becomes tighter
and more accurate.

On Mon, Sep 14, 2020, 2:34 PM Andrey Konovalov <notifications@github.com>
wrote:

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

xairy, 2020-09-15:
Hi! Thank you for the response, this clears some things up! However I still have a few questions.

You mentioned that if one moves faster between two stations, then "the corkscrew essentially gets stretched". Does this only affect the accuracy of the map, or does this also change the size of it? I mean, does one need to do any adjustments to "unstretch" this part of the map afterwards, or does Caveatron takes care of this by itself (e.g. by measuring its speed as it gets moved when walking between two stations)?

Let's say we have three stations in sequence: A, B and C. AFAIU we can use Caveatron to build the map along AB by walking from A to B. Then we can build the map around BC the same way. But then we need the relative position ("inclination/declination, azimuth, and LRUDs"?) between AB and BC to "connect" the two maps, right? Can this relative position be measure with Caveatron or do we need some additional equipment (compass/inclinometer?) for that?

felixcollins, 2022-03-01:
@xairy can I suggest you google "introduction to cave survey".  Or head here: https://www.derekbristol.com/survey-overview
If you think you need a caveatron you should already be quite familiar with cave survey.

xairy, 2022-03-01:
@felixcollins Thanks for the advice! I set aside digging into Caveatron for the time being, but I'll read more about cave survey if I get back to it.

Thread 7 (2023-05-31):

RPLidar A1 Enclosure Base V2 files - hole misaligned

gerowtj, 2023-05-31:
I have tried viewing the .step and .stl files for the "RPLidar A1 Enclosure Base V2" in two different programs.  They both show a hole offset to the left of the recessed feature for the bolt.

If looking from the bottom, with the face that connects to the cavetron lid facing you, its the mounting hole on the left, it shows as being offset to the left of the indentation for the screw clearenace.

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

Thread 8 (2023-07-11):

(Feature) HI50 Laser measure module

burunduk, 2023-07-11:
Please, add this module: Model HI50

| Model                                   | HI50                   |
| --------------------------------------- | ---------------------- |
| Measure accuracy                        | +/- 1mm                |
| Typical accuracy (non reflecting plate) | 0,02-50m               |
| Measurement time                        | 0,3-2s                 |
| Laser Class                             | II                     |
| Voltage                                 | 2.0-3.0V (120mA-300mA) |
| Laser type                              | 635nm, <1mW            |
| Item size                               | 45*25*12mm             |
| Weight Approx                           | 38g                    |
| Use temperature                         | 0C – 40C               |

| ASCII code | HEX  | function                                                       | return            |
| ---------- | ---- | -------------------------------------------------------------- | ----------------- |
|       O    | 0x4F | Turn on the laser.                                             | “,OK!”            |
|       C    | 0x43 | Turn off the laser.                                            | “,OK!”            |
|       S    | 0x53 | Read the state of module.                                      | “18.0’C, 3.0V”    |
|       D    | 0x44 | The automatic measurement process.                             | “12.345m,0079”    |
|       M    | 0x4D | Start slow measurement process                                 | “12.345m,0079”    |
|       F    | 0x46 | Start fast measurement process                                 | “12.345m,0079”    |
|       V    | 0x56 | Query module version information.                              | “170225002929456” |
|       X    | 0x58 | Close the module, close the module and pull the PWR_ON pin low |                   |

* V: “170225002929456” “1702250029” – serial, “29456” – software version
* S: Read temperature and input voltage module
* DMF: “12.345m,0079”: “12.345m” – measurement distance, “0079” quality.
When the ranging is not sucesful, the command will return the error report string “Er.XX!”

01 VBAT too low
02 Internal error, don’t care
03 Module temperature is too low (< -20C)
04 Module temperature is too high (> +40C)
05 Target out of the measure range
06 Invalid measure result
07 Background light is too strong
08 Laser signal is too weak
09 Laser signal is too іекщтп
10 Hardware fault 1
11 Hardware fault 2
12 Hardware fault 3
13 Hardware fault 4
14 Hardware fault 5
15 Laser signal is not stable
16 Hardware fault 6
17 Hardware fault 7

burunduk, 2023-07-11:
In setup hardware configuration it work as JRT in ASCII mode, but in normal mode (manual shoot) its not worked.

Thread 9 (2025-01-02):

C4 Part Number mistake?

ac246ac246, 2025-01-02:
Hi, on the BOM, the link and part number for the push button appear to be wrong. BH16NBSBG should be BH16NBSBRG. the one on the BOM is the green led only and not thee dual LED version. i believe this is the correct version. https://www.digikey.co.uk/en/products/detail/cit-relay-and-switch/BH16NBSBRG/12503584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

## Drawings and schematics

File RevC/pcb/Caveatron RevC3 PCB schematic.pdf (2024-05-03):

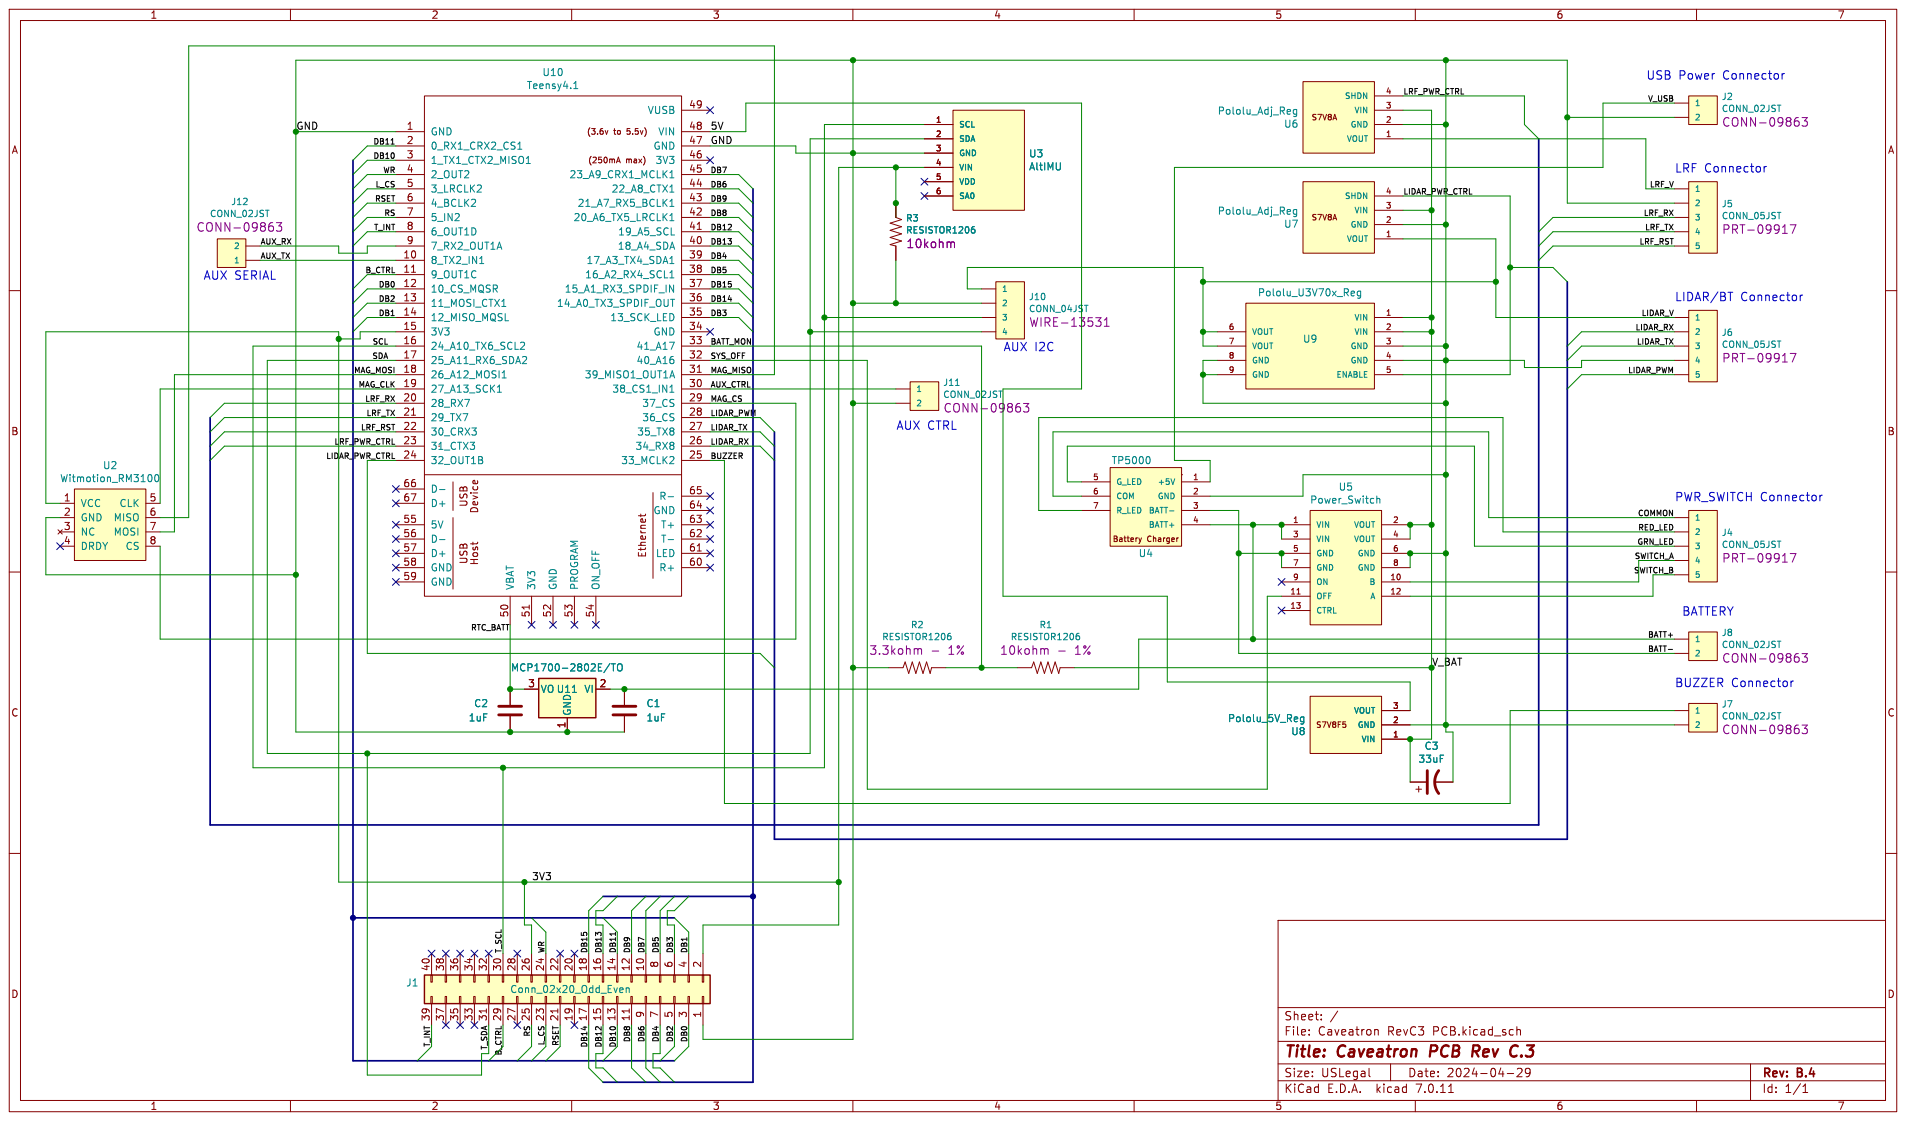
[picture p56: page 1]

Id: 1/1 Title: Caveatron PCB Rev C.3

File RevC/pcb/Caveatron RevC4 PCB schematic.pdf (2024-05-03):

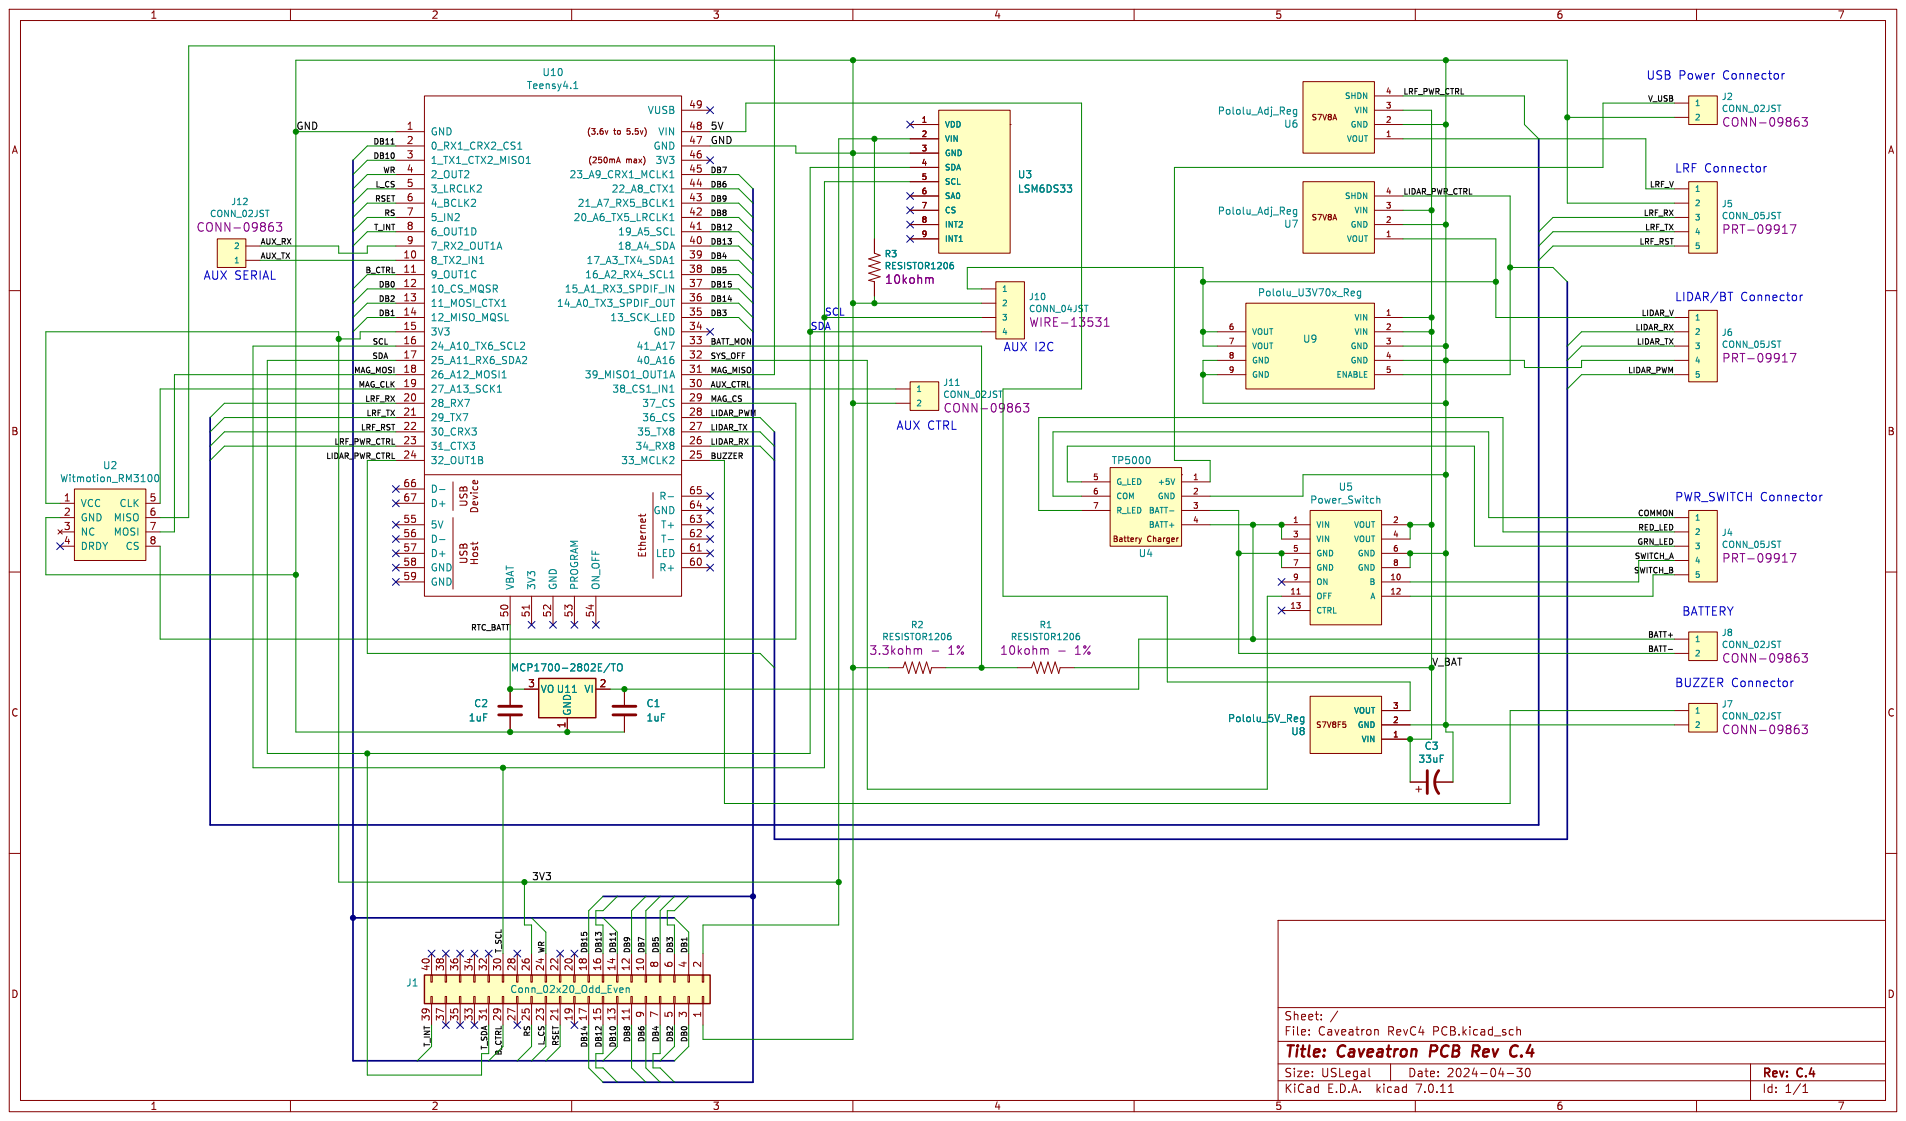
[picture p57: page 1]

Id: 1/1 Title: Caveatron PCB Rev C.4

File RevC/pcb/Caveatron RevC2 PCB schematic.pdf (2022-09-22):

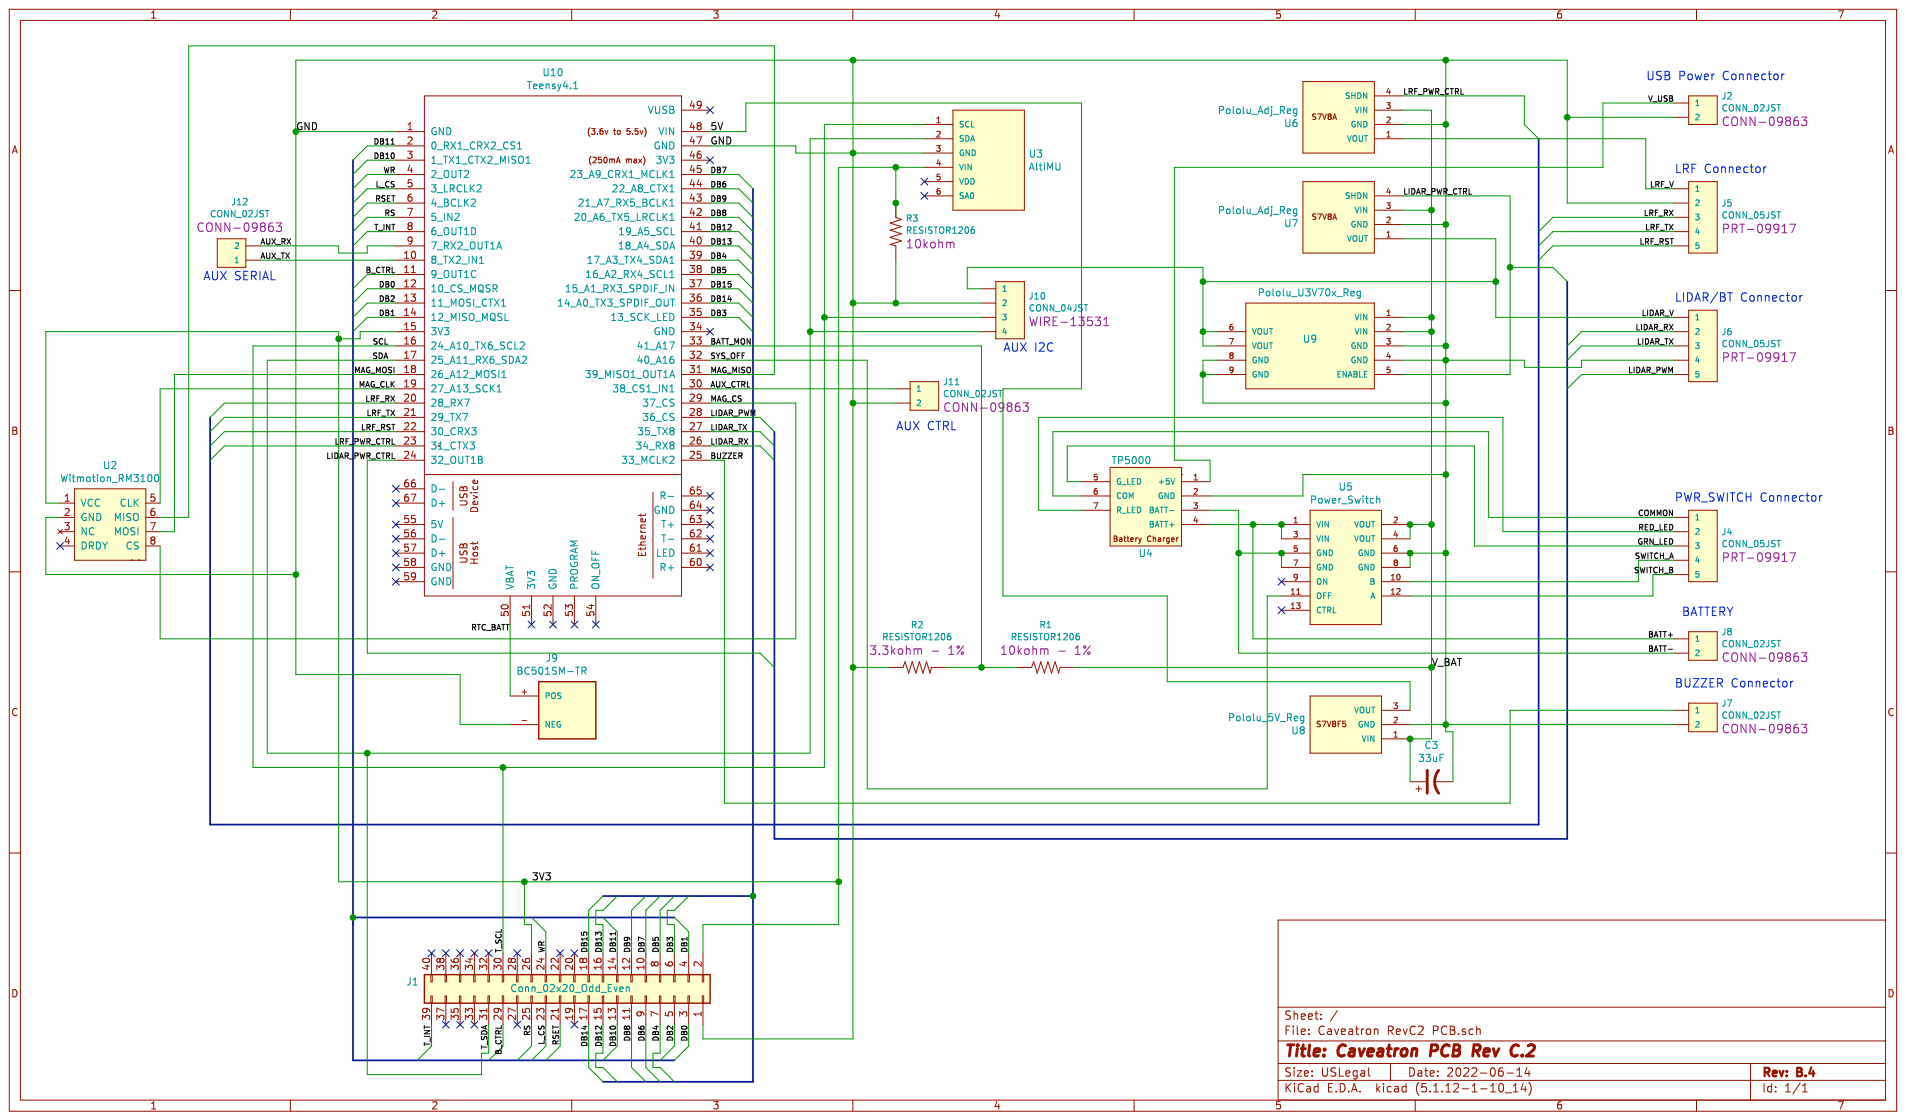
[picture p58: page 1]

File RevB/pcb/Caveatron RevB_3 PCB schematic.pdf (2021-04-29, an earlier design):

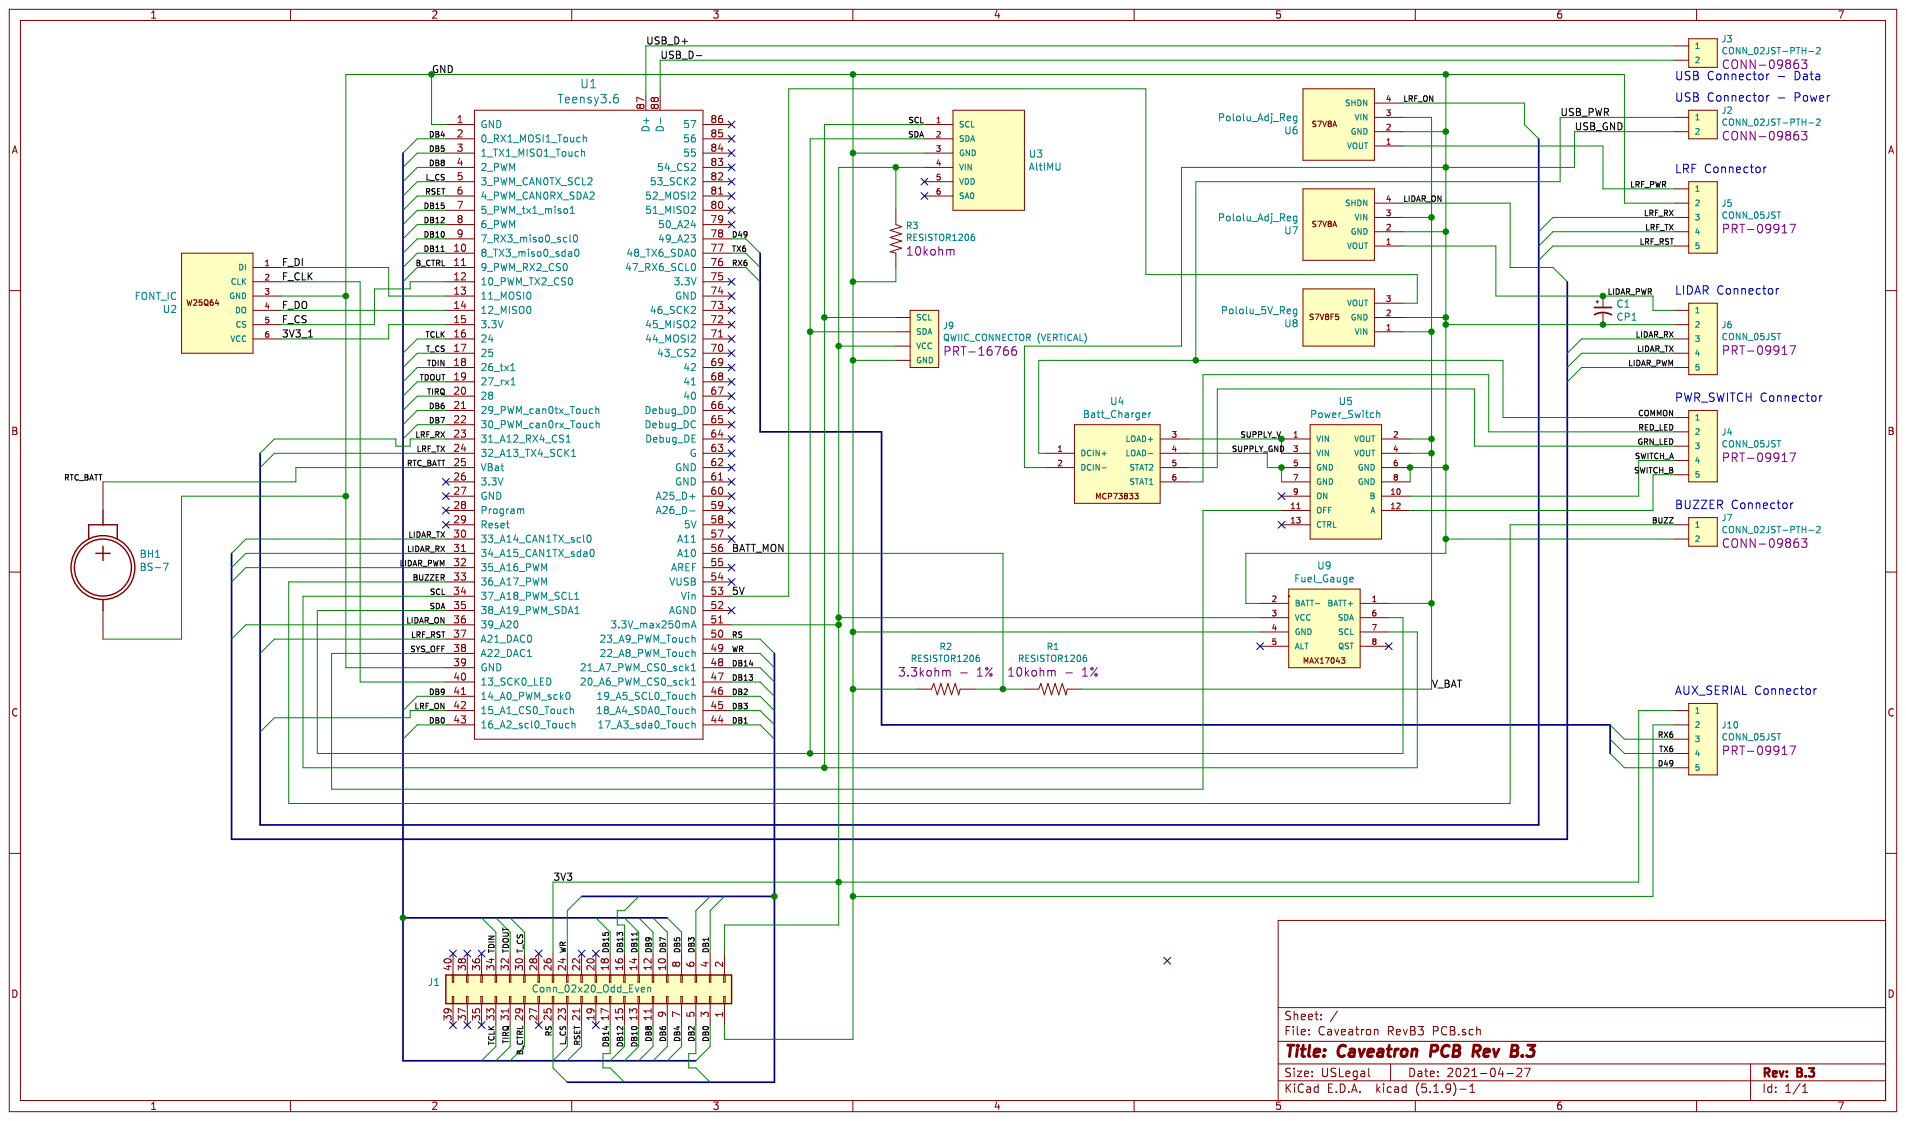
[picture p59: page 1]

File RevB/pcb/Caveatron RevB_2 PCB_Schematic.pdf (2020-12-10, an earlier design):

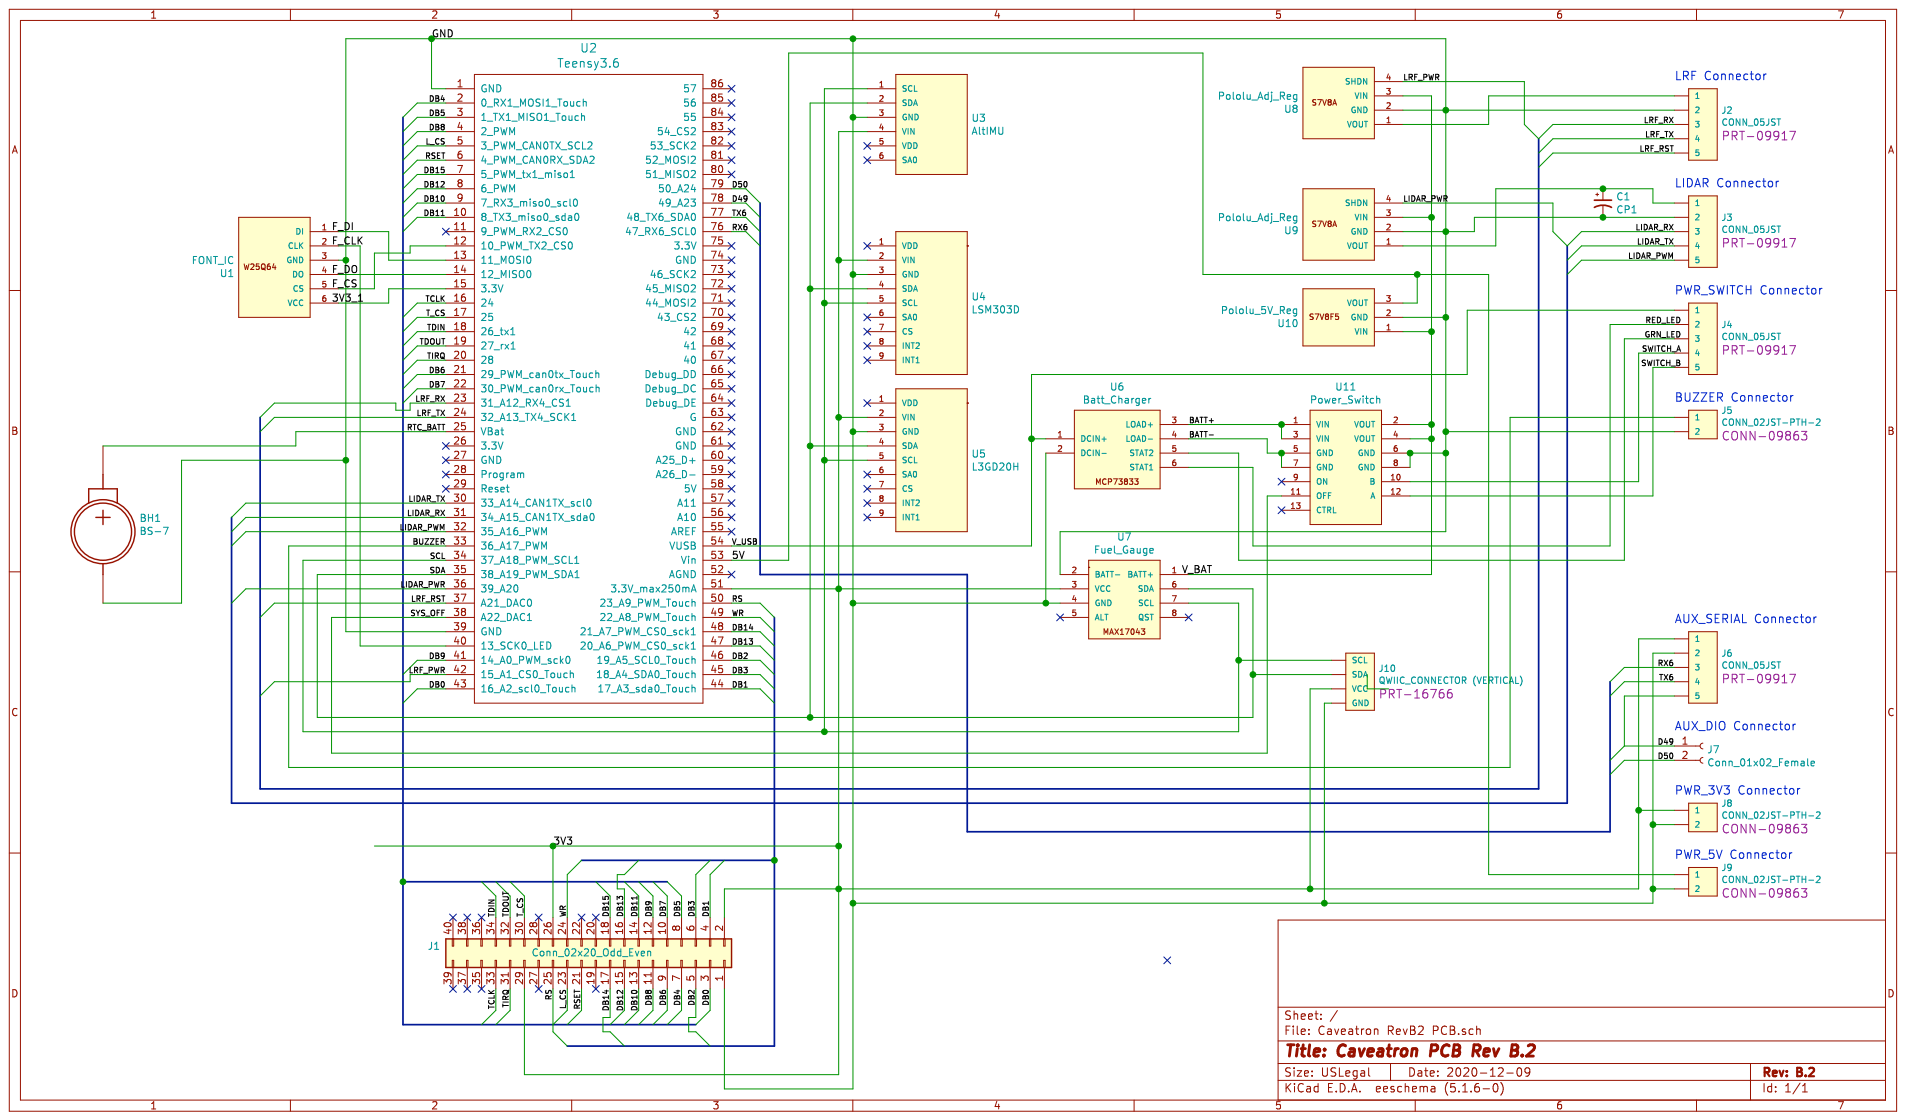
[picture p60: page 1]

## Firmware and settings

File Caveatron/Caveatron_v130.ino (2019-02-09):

/******************************************************************/
//                        CAVEATRON                               //
//                       Version 1.30                             //
/******************************************************************/
// Joe Mitchell, 2019-02-08

// Change Notes(1.21) - not publically released but included in 1.30:
// Fixed bug with RPLIDAR viewing and recording that produced incorrect scan orientation.
// Fixed bug that prevented RPLIDAR scan data from being viewed with the Scan Review function.
// Fixed bug that resulted in some Room Scan data being incorrectly displayed in the Scan Review function.

// Change Notes(1.30):
// CRITICAL: This version requires updating to the following library: Caveatron_GUI 1.3.
// NOTE: It is highly recommended that you also upgrade to the following libraries: Caveatron_Hardware 1.3; URTouch, UTFT, and UTFT_CTE (2019-02-07 versions).
//       These new versions add future support for the Teensy 3.5 and 3.6 processors.
// Added support for dedicated back-sight shots.
// Added screen when entering shot mode to select front/back shot type and preselect recent station codes.
// Added next station code prediction.
// Added tolerance to ignore a single superious magnetometer or accelerometer reading and continue scan
// Fixed bug that would result in erroneous azimuth readings when pointed due south and Passage Mode scan failure.
// Fixed bug that prevented display of the last shot list screen under certain conditions.


// Hardware configuration option - set to 0 for manual, 1 to load from EEPROM
#define AUTO_CONFIG 1

// For manual hardware configuration, set hardware revision and code
char hardwareRev = 'A';
char hardwareCode[] = "12221011110";
uint8_t lidarModuleType;
uint8_t lidarModuleSubType=0;
uint8_t lidarModuleConfig=0;

String softwareVersion = "1.30";

#include <Eigen3210.h>     // Calls main Eigen matrix class library
#include <Eigenvalues>             // Calls inverse, determinant, LU decomp., etc.
using namespace Eigen;    // Eigen related statement; simplifies syntax for declaration of matrices

#include <Wire.h>
#include <UTFT.h>
#include <URTouch.h>
#include <Caveatron_Hardware.h>
#include <UTFT_CTE.h>
#include <UTFT_GHL.h>
#include <Caveatron_GUI.h>
#include <SdFat.h>
#include <MAX17043.h>
#include <SparkFunBQ27441.h>
#include <Sweep.h>
#include <RPLidar.h>
#if defined(_SAM3XA_)
  #include <DueTimer.h>
#endif

#if defined(_SAM3XA_)
  UTFT myGLCD(25,26,27,28);
  URTouch myTouch(6,5,32,3,2);
  SdFat sd;
#endif
Caveatron_Hardware caveatron(&myGLCD, &myTouch);
Caveatron_GUI ctGUI(&caveatron, &myGLCD, &myTouch);

#define min(a,b) ((a)<(b)?(a):(b))
#define max(a,b) ((a)>(b)?(a):(b))

//Variables for GUI timer
#define GUI_check_frequency 8
volatile boolean buttonFlag = false;
volatile boolean interruptLoop = false;
volatile int buttonPressed = -1;
int updateStatusBarCount = 1;

// variables for screens etc
#define screenMainMenu 1
#define screenSettingsMenu 2
#define screenShotMode 3
#define screenPassageMode 4
#define screenRoomMode 5
#define screenManualMode 6
#define screenSurveyMenu 7
#define screenStationEntry 8
#define screenTraverseEntry 9
#define screenSplayEntry 10
#define screenTimeUnits 11
#define screenSDCard 12
#define screenCalibrate 13
#define screenLIDARView 14
#define screenAbout 15
#define screenShotStationSelect 16
#define screenSetTimeDate 21
#define screenTimeDateEntry 22
#define screenSDCardInfo 23
#define screenCompassCalibrate 24
#define screenFileNameEntry 25
#define screenCaveNameEntry 26
#define screenSurveyStats 31
#define screenLinePlot 32
#define screenShotViewer 33
#define screenScanViewer 34
#define screenShotScanReview 35
#define screenAdvancedCal 40
#define screenRawRecord 41
#define screenCalShots 42
#define screenCheckCalibration 43

#define modeNull 0
#define modeShot 1
#define modePassage 2
#define modeRoom 3
#define modeManual 4
#define modeSurvey 5
#define modeSetTime 11
#define modeLIDARView 12
#define modeRawLive 30
#define modeCalRec1000 31
#define modeCalRecCont 32
#define modeCalShots 33
#define modeEditSurvey 40
#define modeViewScans 41

int currentScreen=0;
int currentMode=0;

//Variables for GUI
#define URNnull 0
int pnlTitle, btn1, btn2, btn3, btn4, btn5, btn6, btn7, btn8, txtbox1, pbar1, pbar2, list1;
extern uint8_t BigFont[];
extern uint8_t SmallFont[];
extern const int sin_table[];
extern const int cos_table[];
int btn[50];
int guiStep = 0;
int numOfKeys;
boolean pageLtrKey = false;
boolean shotFlag = false;
boolean holdFlag = false;
boolean errorFlag = false;

//Variables for LCD Screen calibration
unsigned long screenCal[3];

// Variables for RTC
int newSecond, newMinute, newHour, newDay, newMonth, newYear;
String timeSecond, timeMinute, timeHour, dateDay, dateMonth, dateYear;
int timeSetType = 0;
boolean newTimeDate = false;
boolean liveTimeDate = true;

// Variables for Laser Rangefinder
volatile boolean laserFlag = false;
long lastLRFTime=0;
volatile boolean LRFFlag = false;
int LRFRangeCal;

// Variables for LIDAR
Sweep device(Serial2);
RPLidar rplidar;
//ScanPacket reading;
boolean LIDARModule = false;
int LIDARPowerPin, LIDARSensePin1, LIDARSensePin2;
int lidarPacket[4][3];
int angle, lastangle, rot_count, pos_count, data_count, save_count, LIDARstartTime, LIDAR_LRF_Freq;
float lastLIDARdistance, lastLIDARazi, lastLIDARinc, initLIDARdistance;
boolean incShiftFlag, aziShiftFlag, lidarErrorFlag = false;
int idx, LIDAROrientCal;

//Variables for Measurement
float ax, ay, az, rtilt;
float distance, azimuth, inclination, roll, temperature;
float accelCal[12], hardIronCal[3], softIronCal[9], mmAmp[4], mmOff[4];
int16_t firstIMU[6], sphereCenter[3];
int rawIMU[6], ztilt;
boolean rightFlag = false;

//Variables for Station Codes
String stationFrom, stationTo, stationFromNew, stationToNew, stationNext;
String traverseNum, traverseTo, splayNum, splayStation;
float lengthTrav, lengthHoriz, lengthVert;
int numStations, numTraverses, numSplays;
boolean backSight;
typedef struct
  {
    String code;
    int lastTraverseNum;
    int lastSplayNum;
  } scan_list;
  scan_list sta;

//Variables for File and Cave Names
String caveName, caveCode, fileName, fileNameBase, infoBarMsg;
int surveySecond, surveyMinute, surveyHour, surveyDay, surveyMonth, surveyYear;

//Variables for Station Plotting
int plotView, plotGroup;
boolean plotLabels;

//Variables for Shot List
int vectorPage, numVectors;
typedef struct
  {
      String st1_e;
      String st2_e;
      String di_e;
      String az_e;
      String in_e;
      boolean bk_e;
  }  editvector_type;
  editvector_type editVector;

//Variables for Scan List
int scanPage, numScans;

//Variables for SD Card
SdFile theFile, settingsFile, scanFileA, logFile;
ifstream inFile, scanFile;
ofstream outFile, lidarFile;
uint32_t filePosition, streamPositionData, streamPositionScans, streamPositionScanLine, readPosition;
boolean SDFlag, settingsFlag;
boolean fileFlag = false;

//Variables for Buzzer
bool buzOn = false;
boolean buzzerFlag = false;


/////////////////////////////////////////////////////////////////////////////////////////////////////////////////////
//                                          Startup Setup Function
/////////////////////////////////////////////////////////////////////////////////////////////////////////////////////
//

void setup() {
  //Setup LIDAR pins
  LIDARSensePin1 = 21;
  LIDARSensePin2 = 20;
  LIDARPowerPin = 11;
  pinMode(LIDARPowerPin, OUTPUT); 
  pinMode(LIDARSensePin1, INPUT_PULLUP);
  pinMode(LIDARSensePin2, INPUT_PULLUP);
  
  //Setup Serial
  Serial.begin(250000);
  //Serial2.begin(115200);

  //Init SPI
  Wire.begin();
  Wire1.begin();

  delay(500);
  
  //Check for LIDAR Module
  boolean LIDARsense1 = digitalRead(LIDARSensePin1);
  boolean LIDARsense2 = digitalRead(LIDARSensePin2);
  if ((LIDARsense1==LOW)&&(LIDARsense2==LOW)) {
    LIDARModule = true;
    lidarModuleType = 3;
  } else if (LIDARsense1==LOW) {
    LIDARModule = true;
    lidarModuleType = 1
    ;
  } else if (LIDARsense2==LOW) {
    LIDARModule = true;
    lidarModuleType = 2;
  } else LIDARModule = false;

  if (LIDARModule==true) digitalWrite(LIDARPowerPin, HIGH);

  //Set Calibration Parameters and Hardware Version Specific Settings
  if (AUTO_CONFIG==1) {
    LoadCalibrationParameters();
    caveatron.Init();
  }
  else {
    LoadTestCalibrationParameters();
    caveatron.Init(hardwareRev, hardwareCode);
  }
  
  //Setup SD card
  caveatron.SD_Init();
  
  //Setup Laser Rangefinder
  caveatron.LRF_Init();
  caveatron.LRF_SetMode(0);

  //Setup Battery Gauge
  caveatron.BATT_Init();
  
  //Setup IMU module
  caveatron.IMU_Init();
  
  //Init Buzzer
  caveatron.BUZZ_Init();
  delay(100);

  //Init GUI
  myTouch.InitTouch(PORTRAIT, screenCal[0], screenCal[1], screenCal[2]);
  caveatron.LCD_Init();
  myGLCD.clrScr();
  delay(500);
  ctGUI.InitGUI();
  ctGUI.print("", 160, 0, caveatron.FONT_19, 2, CENTER_J, BLACK_STD, BLACK_STD);
  
  delay(500);

  //Configure LIDAR
  if (LIDARModule==true) caveatron.LIDAR_Init(lidarModuleType);
  digitalWrite(LIDARPowerPin, LOW);

  //If USB connected from Caveatron Connect software, start USB connect mode
  if (Serial.available() > 0) {}
  if (Serial.read() == '?') USBConnectMode();

  //Init SD
  InitSD();

  delay(100);
  CreateScreen(screenMainMenu);

  //Start GUI Interrupt Timer  
  Timer4.attachInterrupt(GUI_Handler).setFrequency(GUI_check_frequency).start();
  
}


/////////////////////////////////////////////////////////////////////////////////////////////////////////////////////
//                                           Main Function Loop
/////////////////////////////////////////////////////////////////////////////////////////////////////////////////////
//

void loop() {
  
  //If button pressed, send to handler
  if (buttonFlag==true){
    Timer4.stop();
    OnButtonPress(buttonPressed);
    Timer4.start();
  }

  //If interrupt timer triggers (@8 Hz), take action depending on mode
  if (interruptLoop==true) {
    switch (currentMode) {
      case modeShot:
        if (shotFlag==true) {
          TakeShot();
        }
        break;
      case modeManual:
        if (holdFlag==false) {
          if (shotFlag==true) {
            holdFlag = true;
            TakeShot();
          }
          else {
            Timer4.stop();
            UpdateLiveData();
            Timer4.start();
          }
        }
        break;
      case modeSetTime:
        DisplayTimeDate();
        break;
      case modeRawLive:
      case modeCalRec1000:
      case modeCalRecCont:
        if (currentScreen!=screenFileNameEntry) UpdateRawDisplay();
        break;
      case modeCalShots:
        UpdateCalShotsDisplay();
        break;
    }
  }
  //Set false to await next interrupt
  interruptLoop = false;  
}

////////////////////////////////////////////////////////////////////////////////////////////////////////////////////////////
//                                          GUI General and Main Menu Setup Functions
/////////////////////////////////////////////////////////////////////////////////////////////////////////////////////////////
//

// Function for calling functions to setup new menu screens depending on screen code
void CreateScreen(int screen) {
  // Set global variable to record which screen is in view
  currentScreen=screen; 
  // Clear all the data and the screen
  ctGUI.clearAllObjects();
  myGLCD.clrScr();
  
  //Select screen to setup
  boolean fileFlag = false;
  switch (currentScreen) {
    case screenMainMenu: 
      MainMenuSetup();
      break;
    case screenSettingsMenu: 
      SettingsMenuSetup();
      break;
    case screenShotStationSelect:
      if (SDFlag==false) ErrorBox("SD Card", "Not Found", "", 99);
      else fileFlag = OpenSurveyFiles();
      if ((SDFlag==true) && (fileFlag==true)) ShotStationSetup();
      break;
    case screenStationEntry:   
      if (currentMode!=modeShot) {
        if (SDFlag==false) ErrorBox("SD Card", "Not Found", "", 99);
        else fileFlag = OpenSurveyFiles();
        if ((SDFlag==true) && (fileFlag==true)) StationEntrySetup();
      } else StationEntrySetup();
      break;
    case screenTraverseEntry:
      TraverseEntrySetup();
      break;
    case screenSplayEntry:
      SplayEntrySetup();
      break;
    case screenShotMode:
      ShotModeSetup();
      break;
    case screenPassageMode:
      PassageModeSetup();
      break;
    case screenRoomMode:
      RoomModeSetup();
      break;
    case screenManualMode:
      ManualModeSetup();
      break;
    case screenSurveyMenu:
      if (SDFlag==false) ErrorBox("SD Card", "Not Found", "", 99);
      else SurveyMenuSetup();
      break;
    case screenCaveNameEntry:
      CaveNameEntrySetup();
      break;
    case screenSurveyStats:
      if (settingsFlag==false) ErrorBox("Settings File", "Not Found -", "Start New Survey", 99);
      else SurveyStatsSetup();
      break;
    case screenLinePlot:
      LinePlotSetup();
      break;
    case screenShotScanReview:
      ShotScanReviewSetup();
      break;
    case screenShotViewer:
      ShotViewerSetup(1);
      break;
    case screenScanViewer:
      ScanViewerSetup(1);
      break;
    case screenTimeUnits:
      TimeUnitsSetup();
      break;
    case screenSetTimeDate:
      SetTimeDateSetup();
      break;
    case screenTimeDateEntry:
      TimeDateEntrySetup();
      break;
    case screenSDCard:
      if (SDFlag==false) ErrorBox("SD Card", "Not Found", "", 99);
      else SDCardMenuSetup();
      break;
    case screenCalibrate:
      CalibrateMenuSetup();
      break;
    case screenAbout:
      AboutScreenSetup();
      break;
    case screenCompassCalibrate:
      CompassCalibrateSetup();
      break;
    case screenCheckCalibration:
      CheckCalibrationSetup();
      break;
    case screenAdvancedCal:
      AdvancedCalMenuSetup();
      break;
    case screenRawRecord:
      RawRecordSetup();
      break;
    case screenCalShots:
      CalShotsSetup();
      break;
    case screenFileNameEntry:
      FileNameEntrySetup();
      break;
    case screenLIDARView:
      LIDARViewSetup();
      break;
  }
  
  // Draw screen to LCD
  ctGUI.redrawAllObjects();
}

// Setup Main Menu Screen
void MainMenuSetup(){
  drawStatusBar("CAVEATRON");
  drawInfoBar(infoBarMsg);
  guiStep = 0;
  ctGUI.addIconButton(12,30,140,130,BUTTON_STD,"SHOT",caveatron.FONT_28,10,caveatron.iSHOT,62,50,optVisible,1);
  if(LIDARModule) {
    ctGUI.addIconButton(167,30,140,130,BUTTON_STD,"PASSAGE",caveatron.FONT_28,10,caveatron.iPASSAGE,62,50,optVisible,2);
    ctGUI.addIconButton(167,171,140,130,BUTTON_STD,"ROOM",caveatron.FONT_28,10,caveatron.iROOM,62,50,optVisible,3);
    ctGUI.addIconButton(12,171,140,130,BUTTON_STD,"MANUAL",caveatron.FONT_28,10,caveatron.iMANUAL,62,50,optVisible,4);
  }
  else {
    ctGUI.addIconButton(167,30,140,130,BUTTON_STD,"MANUAL",caveatron.FONT_28,10,caveatron.iMANUAL,62,50,optVisible,4);
  }
  ctGUI.addIconButton(12,321,140,130,BUTTON_STD,"SURVEY",caveatron.FONT_28,10,caveatron.iSURVEY,62,50,optVisible,5);
  ctGUI.addIconButton(167,321,140,130,BUTTON_STD,"SETTINGS",caveatron.FONT_28,10,caveatron.iSETTINGS,62,50,optVisible,6);
  myGLCD.setColor(GRAY_025);
  myGLCD.drawLine(12,311,307,311);
}

//Setup Settings Menu Screen
void SettingsMenuSetup(){
  drawStatusBar("SETTINGS");
  drawInfoBar("SURVEY: "+caveName);

  ctGUI.addIconButton(12,30,140,130,BUTTON_STD,"TIME",caveatron.FONT_28,10,caveatron.iTIME,62,50,optVisible,1);
  ctGUI.addIconButton(167,30,140,130,BUTTON_STD,"SD CARD",caveatron.FONT_28,10,caveatron.iSD,62,50,optVisible,2);
  ctGUI.addIconButton(12,171,140,130,BUTTON_STD,"CALIBRATE",caveatron.FONT_28,10,caveatron.iCALIBRATE,62,50,optVisible,3);
  if(LIDARModule) {
    ctGUI.addIconButton(167,171,140,130,BUTTON_STD,"LIDAR",caveatron.FONT_28,10,caveatron.iLIDAR,62,50,optVisible,4);
  }
  ctGUI.addIconButton(12,321,140,130,BUTTON_STD,"ABOUT",caveatron.FONT_28,10,caveatron.iABOUT,62,50,optVisible,5);
  ctGUI.addIconButton(167,321,140,130,BUTTON_STD,"MAIN MENU",caveatron.FONT_28,10,caveatron.iRETURN,62,50,optVisible,6);
  myGLCD.setColor(GRAY_025);
  myGLCD.drawLine(12,311,307,311);
}

////////////////////////////////////////////////////////////////////////////////////////////////////////////////////////////
//                                                 GUI Interupt Routines
/////////////////////////////////////////////////////////////////////////////////////////////////////////////////////////////
//

// fast ticks for Due GUI interupt
volatile int btnFound;
volatile unsigned long int GUI_InterruptTime;
unsigned long int GUI_ButtonLastPressedTime=0;
//
//  DueGUI Interupt handler routine
//
void GUI_Handler(){
  //
  // We don't want timer called whilst it's being handled.
  //
  GUI_InterruptTime=millis();
  //
  // routine is called several times per second ie "ticksPerSecond".
  if ((myTouch.dataAvailable()==true) || (ctGUI.anyButtonPressed==true)){
    if ((GUI_ButtonLastPressedTime+200)<GUI_InterruptTime){
      GUI_ButtonLastPressedTime=GUI_InterruptTime;
      btnFound=ctGUI.checkAllButtons(OnRelease);
      //If button found set button flag
      if (btnFound!=-1){
        buttonFlag=true;
        buttonPressed = btnFound;
      }
    }
  }
  //Update status bar every 10 seconds
  if (updateStatusBarCount>(GUI_check_frequency*10)) {
    if ((currentMode!=modePassage) && (currentMode!=modeRoom) && (currentScreen!=screenLinePlot)) { //Don't update under these modes and screens
      drawStatusBar("");
      updateStatusBarCount=1;
    }
  }
  updateStatusBarCount++;
  
  interruptLoop = true;
  // Ok interupt handler is finished. 
}


// Function for calling button press handler depending on current screen code
void OnButtonPress(int btnFound){
  int URN=ctGUI.GUIobject_UniqueReference[btnFound];
  if ((URN==98)||(URN==99)) ErrorBoxHandler(URN);
  switch(currentScreen) {
    case screenMainMenu: 
      MainMenuHandler(URN);
      break;
    case screenSettingsMenu:
      SettingsMenuHandler(URN);
      break;
    case screenStationEntry:
    case screenTraverseEntry: 
    case screenSplayEntry:
    case screenCaveNameEntry: 
    case screenTimeDateEntry:
      KeyPadHandler(URN);
      break;
    case screenShotStationSelect:
      ShotStationSelectHandler(URN);
      break;
    case screenShotMode: 
      ShotModeHandler(URN);
      break;
    case screenPassageMode: 
      PassageModeHandler(URN);
      break;
    case screenRoomMode: 
      RoomModeHandler(URN);
      break;
    case screenManualMode: 
      ManualModeHandler(URN);
      break;
    case screenSurveyMenu: 
    case screenSurveyStats:
      SurveyMenuHandler(URN);
      break;
    case screenShotScanReview:
      ShotScanReviewHandler(URN);
      break;
    case screenShotViewer:
      ShotViewerHandler(URN);
      break;
    case screenScanViewer:
      ScanViewerHandler(URN);
      break;
    case screenLinePlot:
      LinePlotHandler(URN);
      break;
    case screenTimeUnits:
      TimeUnitsMenuHandler(URN);
      break;
    case screenSetTimeDate:
      SetTimeDateHandler(URN);
      break;
    case screenAbout:
    case screenSDCard:
      SDCardMenuHandler(URN);
      break;
    case screenCalibrate:
      CalibrateMenuHandler(URN);
      break;
    case screenCompassCalibrate:
      CompassCalibrateHandler(URN);
      break;
    case screenCheckCalibration:
      CheckCalibrationHandler(URN);
      break;
    case screenAdvancedCal:
      AdvancedCalMenuHandler(URN);
      break;
    case screenRawRecord:
      RawRecordHandler(URN);
      break;
    case screenCalShots:
      CalShotsHandler(URN);
      break;
    case screenFileNameEntry:
      FileNameEntryHandler(URN);
      break;
  }
  //Reset button flag have buttons handled
  buttonFlag=false;  
}  
    
////////////////////////////////////////////////////////////////////////////////////////////////////////////////////////////
//                                          Main Menu and Settings Menu Handlers
/////////////////////////////////////////////////////////////////////////////////////////////////////////////////////////////
//

//Button press handler for Main Menu screen
void MainMenuHandler(int URN) {  
  switch (URN) {
    case 1:
      currentMode = modeShot; 
      guiStep++;
      CreateScreen(screenShotStationSelect);
      break;
    case 2:
      currentMode = modePassage; 
      guiStep++;
      CreateScreen(screenStationEntry);
      break;
    case 3:
      currentMode = modeRoom; 
      guiStep++;
      CreateScreen(screenStationEntry);
      break;
    case 4:
      currentMode = modeManual;
      CreateScreen(screenManualMode);
      break;
    case 5:
      currentMode = modeSurvey; 
      guiStep++;    
      CreateScreen(screenSurveyMenu);
      break;
    case 6:
      CreateScreen(screenSettingsMenu);
      break;
  }
}

//Button press handler for Settings Menu screen
void SettingsMenuHandler(int URN) {  
  switch (URN) {
    case 1:
      guiStep++;
      CreateScreen(screenTimeUnits);
      break;
    case 2:
      guiStep++;
      CreateScreen(screenSDCard);
      break;
    case 3:
      guiStep++;
      CreateScreen(screenCalibrate);
      break;
    case 4:
      currentMode = modeLIDARView;
      guiStep++;
      CreateScreen(screenLIDARView);
      break;
    case 5:
      guiStep++;
      CreateScreen(screenAbout);
      break;
    case 6:
      CreateScreen(screenMainMenu);
      break;
  }
}

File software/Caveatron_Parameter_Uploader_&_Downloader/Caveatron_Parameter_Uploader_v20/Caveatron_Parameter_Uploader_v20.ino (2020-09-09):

/*****************************************************************/
//             Caveatron Parameter Uploader                      //
//                       Version 2.0                             //
/*****************************************************************/
// Joe Mitchell, 2019-12-15
// Used to Upload Calibration Parameters to the Caveatron EEPROM
// Fill in your calibration parameters in the "Calibration_Parameters" tab

#include <UTFT.h>
#include <EEPROM.h>

UTFT myGLCD(CTE35IPS,23,22,3,4);

extern uint8_t BigFont[];
extern uint8_t SmallFont[];

// Switches for Parameter Upload
// Set to 1 to load, 0 to ignore
//*******************************

boolean loadSerialNum = 0;          // Unit Serial Number, 5 char
boolean loadHardwareCode = 0;       // Unit Hardware Code, 12 char
boolean loadScreenCal = 0;          // LCD Display Calibration, 3x1 array of 10 char

boolean loadAccelCal = 0;           // Accelerometer Offsets and Alignment, 3x4 float array

boolean loadMagAlignCal = 0;   // Magnetometer Alignment, 8x1 float array
boolean loadMagHSCal = 0;      // **Loaded through internal calibration - Magnetometer Hard and Soft Iron, 3x4 float array

boolean loadGyroCal = 0;      //Gyroscope Zero Rate Offset, 3x1 float array

boolean loadLidarWindowCorners = 0;      //Gyroscope Zero Rate Offset, 3x1 float array
boolean loadLidarOrientCal = 0;   // LIDAR Rotation Orientation, 1 float
boolean loadLidarWindowCorrection = 0;   // LIDAR Rotation Orientation, 1 float
boolean loadLRFRangeCal = 0;        // LRF Distance, 1 float

boolean initalizePrefs = 0;   //Set preference values to "1"

//*******************************

// EEPROM Calibration Parameter Addresses
// 1 page is 0x020 in length
#define ADDR_SERIAL_NUM     0x00        //Uses 1 page
#define ADDR_HARDWARE_CODE    0x020     //Uses 1 page
#define ADDR_SCREEN_CAL     0x080       //Uses 3 pages
#define ADDR_ACC_CAL      0x200         //Uses 4 pages
#define ADDR_MAG_ALIGNCAL 0x300   //Uses 2 pages
#define ADDR_MAG_HSCAL  0x400     //Uses 4 pages
#define ADDR_GYR_CAL  0x600     //Uses 4 pages
#define ADDR_LID_CORNERS 0x700    //Users 4 pages
#define ADDR_LID_ORIENTCAL   0x800     //Uses 1 page
#define ADDR_LRF_RANGECAL   0x860     //Uses 1 page
#define ADDR_LID_WINCORRECT   0xA00   //Uses 722 bytes

// EEPROM Preferences Addresses
#define ADDR_LIDARSPEED_PREF  0x900
#define ADDR_LIDARRATE_PREF 0x901
#define ADDR_LRFRATE_PREF 0x905
#define ADDR_SHUTDOWN_PREF  0x910

extern char serialNumber[];
extern char hardwareCode[];
extern char screenCal[3][11];
extern float accCal[4][3];
extern float magAlignCal[8];
extern float magCal[4][3];
extern float gyrCal[3];
extern float lidarCorners[4][2];
extern float lidarOrientCal[1];
extern float LRFRangeCal[1];
extern int8_t lidarWindowCorrectSettings[2];
extern int8_t lidarWindowCorrection[720];


void setup() {
  //Init Serial
  Serial.begin(250000);

  //Init GUI
  myGLCD.invert_colors = true;
  myGLCD.InitLCD(PORTRAIT);
  myGLCD.clrScr();
  myGLCD.setBackColor(0, 0, 0);
  myGLCD.setFont(BigFont);
  delay(500);

  int y = 20;
  
  if (loadSerialNum) {
    UploadSerialNumber();
    delay(100);
    if (CheckSerialNumber()) {
      myGLCD.setColor(0, 255, 0);
      myGLCD.print("Serial Num Loaded", CENTER, y);
    } else {
      myGLCD.setColor(255, 0, 0);
      myGLCD.print("Serial Num Failed", CENTER, y);
    }
    y=y+20;
  }
  if (loadHardwareCode) {
    UploadHardwareCode();
    delay(100);
    if (CheckHardwareCode()) {
      myGLCD.setColor(0, 255, 0);
      myGLCD.print("Hardware Code Loaded", CENTER, y);
    } else {
      myGLCD.setColor(255, 0, 0);
      myGLCD.print("Hardware Code Failed", CENTER, y);
    }
    y=y+20;
  }
  if (loadScreenCal) {
    UploadScreenCal();
    delay(100);
    if (CheckScreenCal()) {      
      myGLCD.setColor(0, 255, 0);
      myGLCD.print("Screen Cal Loaded", CENTER, y);
    } else {
      myGLCD.setColor(255, 0, 0);
      myGLCD.print("Screen Cal Failed", CENTER, y);
    }
    y=y+20;
  }
  if (loadAccelCal) {
    UploadAccelerometerCal();
    delay(100);
    if (CheckAccelerometerCal()) {
      myGLCD.setColor(0, 255, 0);
      myGLCD.print("Accel Cal Loaded", CENTER, y);
    } else {
      myGLCD.setColor(255, 0, 0);
      myGLCD.print("Accel Cal Failed", CENTER, y);
    }
    y=y+20;
  }
  if (loadMagAlignCal) {
    UploadMagnetometerAlignCal();
    delay(100);
    if (CheckMagnetometerAlignCal()) {      
      myGLCD.setColor(0, 255, 0);
      myGLCD.print("Mag Al Cal Loaded", CENTER, y);
    } else {
      myGLCD.setColor(255, 0, 0);
      myGLCD.print("Mag Al Cal Failed", CENTER, y);
    }
    y=y+20;
  }
  if (loadMagHSCal) {
    UploadMagnetometerHSCal();
    delay(100);
    if (CheckMagnetometerHSCal()) {
      myGLCD.setColor(0, 255, 0);
      myGLCD.print("MagHS Cal Loaded", CENTER, y);
    } else {
      myGLCD.setColor(255, 0, 0);
      myGLCD.print("MagHS Cal Failed", CENTER, y);
    }
    y=y+20;
  }
  if (loadGyroCal) {
    UploadGyroCal();
    delay(100);
    if (CheckGyroCal()) {      
      myGLCD.setColor(0, 255, 0);
      myGLCD.print("Gyro Cal Loaded", CENTER, y);
    } else {
      myGLCD.setColor(255, 0, 0);
      myGLCD.print("Gyro Cal Failed", CENTER, y);
    }
    y=y+20;
  }
  if (loadLidarWindowCorners) {
    UploadLidarCornersCal();
    delay(100);
    if (CheckLidarCornersCal()) {
      myGLCD.setColor(0, 255, 0);
      myGLCD.print("Lidar Corners Loaded", CENTER, y);
    } else {
      myGLCD.setColor(255, 0, 0);
      myGLCD.print("Lidar Corners Failed", CENTER, y);
    }
    y=y+20;
  }
  if (loadLidarOrientCal) {
    UploadLidarOrientCal();
    delay(100);
    if (CheckLidarOrientCal()) {
      myGLCD.setColor(0, 255, 0);
      myGLCD.print("LIDAR Orient Loaded", CENTER, y);
    } else {
      myGLCD.setColor(255, 0, 0);
      myGLCD.print("LIDAR Orient Failed", CENTER, y);
    }
    y=y+20;
  }
  if (loadLRFRangeCal) {
    UploadLRFRangeCal();
    delay(100);
    if (CheckLRFRangeCal()) {
      myGLCD.setColor(0, 255, 0);
      myGLCD.print("LRF Range Loaded", CENTER, y);
    } else {
      myGLCD.setColor(255, 0, 0);
      myGLCD.print("LRF Range Failed", CENTER, y);
    }
    y=y+20;
  }
  if (loadLidarWindowCorrection) {
    UploadLidarWindowCorrection();
    delay(100);
    if (CheckLidarWindowCorrection()) {
      myGLCD.setColor(0, 255, 0);
      myGLCD.print("Window Corr Loaded", CENTER, y);
    } else {
      myGLCD.setColor(255, 0, 0);
      myGLCD.print("Window Corr Failed", CENTER, y);
    }
    y=y+20;
  }
  if (initalizePrefs) {
    InitializePrefs();
    delay(100);
    if (CheckPrefs()) {
      myGLCD.setColor(0, 255, 0);
      myGLCD.print("Preferences Inited", CENTER, y);
    } else {
      myGLCD.setColor(255, 0, 0);
      myGLCD.print("Pref Init Failed", CENTER, y);
    }
    y=y+20;
  }
  myGLCD.setColor(255, 255, 255);
  myGLCD.print("DONE", CENTER, y);
  
}

void loop() {
  // put your main code here, to run repeatedly:

}
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

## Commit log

2018-01-27 Fixed several serious bugs in user calibration routine
2018-03-05 Release Version 1.0 of the Caveatron Firmware
    Initial release of Caveatron firmware
    Initial release of calibration parameter uploader and downloader
2018-05-05 Add a couple of casts to silence compilation warnings
2018-08-01 Update Caveatron software to version 1.10
    v1.10 adds several new features, the most signficant of which is that you can now review LIDAR data from a completed scan.
    - Added "View LIDAR Scans" function to view list of LIDAR scans in the current survey and basic information about them. Scans are displayed in order from newest to oldest.
    - Added function to select any completed LIDAR scan data in the current survey and view it on screen. A plan or profile view can be chosen and a 2D plot of the data in a horizontal or vertical slice 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
2018-12-16 Incorporates RP LIDAR modules, adds calibration checker, and bugfixes
    [Calibration_Parameters.ino]
2019-02-09 Libraries Update for Caveatron 1.3
    Updated to add future support of Teensy 3.5/3.6
2019-02-09 Adds back-sights, shot code selection screen, better scan error handling, and bugfixes
    [Caveatron_v130.ino]
2019-11-07 Update with new calibration loading & saving method plus several improvements & bug fixes
    Change Notes(1.40):
    CRITICAL: You must update the Caveatron_Hardware library to v1.4.
    When creating a new survey, calibration parameters are now stored in a .IMU file
    Added ability to load and save calibration parameters from/to a file on the SD card (use of Caveatron_Downloader/Uploader sketch no longer required).
    Added compatibility with Caveatron Connect 1.1 to provide for transfer of .IMU calibration files from a PC to the Caveatron SD card.
    Added magnetometer alignment to the View IMU Calibration screen
    Fixes to improve LRF turn-on reliability
    Reorganized Calibration menu screens
    Added a dialog box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
2020-01-26 New Caveatron Version - Rev B
    Reorganize repository and add information on Caveatron Rev B. Previous Rev A Caveatron info moved to new caveatron_rev-A_version repository.
    [AltIMU Bracket v1.stl, Board support post v2.stl, Buzzer Clamp v7.stl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]
2020-01-29 Added 3D parts description document
    [Battery Charging Board Support Post v2.stl, LCD Clamp v4.stl]
2020-02-19 Minor BOM revisions and addition
2020-02-21 Add drawings of LRF and LIDAR windows + BOM revision
2020-03-05 Instructions and Spreadsheets for Setup and Initial Calibration
    [Caveatron Accelerometer & Gyro Calibration Calculator v2.xlsx, Caveatron Magnetometer Calibration Calculator.xlsx]
2020-03-05 Font & Graphics File for SPI Flash IC
2020-03-05 Fonts & Graphics for SPI Flash - Used with Caveatron_Setup firmware
2020-04-06 New Wire Harness Assembly Instruction
2020-04-07 New Wire Harness Assembly document
2020-04-10 New Assembly Instructions Document
2020-04-10 Updated BOM
2020-04-10 New Assembly Instructions and Updated Readme
2020-05-10 Fixed to prevent small LRF tilt
    [LRF Support Bracket v2.stl, LRF Support Bracket v3.stl, LRF Support Post v3.stl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]
2020-05-10 Add STEP file versions for all 3D printed parts
    [AltIMU Bracket v1.step, Board support post v2.step, Buzzer Clamp v7.step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]
2020-05-10 Add Fusion360 native versions of all 3D printed parts
    [AltIMU Bracket v1.f3d, Board support post v2.f3d, Buzzer Clamp v7.f3d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]
2020-05-11 Add KiCad PCB project files
2020-05-29 Fixed minor issue found by Craig Hamer
    [RPLIDAR Enclosure Base v6.f3d, RPLIDAR Enclosure Base v6.step, RPLIDAR Enclosure Base v6.stl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]
2020-05-29 Fixed swapped LRF wire found by Dave Jones
2020-12-10 Revised PCB design for BuyDisplay
    [Caveatron RevB_2 PCB.kicad_pcb, Caveatron RevB_2 PCB.sch]
2020-12-12 New lid design for BuyDisplay 3.5" LCD module
    [Caveatron Main Enclosure Lid - BuyDisplay v2.f3d, Caveatron Main Enclosure Lid - BuyDisplay v2.step, Caveatron Main Enclosure Lid - BuyDisplay v2.stl]
2020-12-14 Posting of PCB rev B.2 Gerbers
    [Caveatron RevB_2 PCB.kicad_pcb, Caveatron RevB_2 PCB.sch]
2020-12-18 Fixed cell positions in result tab to match IMU file
    [Caveatron Accelerometer & Gyro Calibration Calculator v2.xlsx, Caveatron Accelerometer & Gyro Calibration Calculator v3.xlsx]
2021-02-28 Added Kicad files for PCB B2 and renamed others
2021-03-25 Updated BOM with new links and corrections
2021-04-27 Site Reorganization
    [Caveatron Accelerometer & Gyro Calibration Calculator v3.xlsx, Caveatron Magnetometer Calibration Calculator.xlsx]
2021-04-29 Added Rev B3 PCB design files
2021-08-03 New version of RPLIDAR lid and 3D printed parts document
    [RPLIDAR Enclosure Lid - No Windows (Bottom) v4.stl, RPLIDAR Enclosure Lid - No Windows (Top) v3.stl]
2022-09-22 Add Rev C folder
    [AltIMU Bracket v1.f3d, AltIMU Bracket v1.step, AltIMU Bracket v1.stl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]
2022-11-13 Rev C enclosure 3D print files
    [Buzzer Clamp v1.stl, Caveatron Rev C Base v16.stl, Caveatron Rev C Lid v5.stl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]
2022-12-10 Added Rev C STEP files
    [Buzzer Clamp v1.step, Caveatron Rev C Base v16.step, Caveatron Rev C Lid v5.step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]
2023-01-13 Updated files
    [Caveatron Rev C Lid v5.step, Caveatron Rev C Lid v5.stl, Caveatron Rev C Lid v6.step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]
2023-01-17 Create Caveatron Rev C Assembly Instructions - 2023-01-16.pdf
2023-01-27 Updated Assembly Instructions
2023-02-06 Minor 3D print file revisions
    [LCD Clamp v1.step, LCD Clamp v1.stl, LCD Clamp v2.step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]
2023-06-08 Fixed problem in file
    [RPLIDAR A1 Enclosure Base v2.step, RPLIDAR A1 Enclosure Base v2.stl, RPLIDAR A1 Enclosure Base v3.step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]
2023-08-24 Create RTC regulator retrofit 23-08-23.pdf
2024-05-03 Release of new PCB revisions
    [LSM6DS33 Bracket for 7mm headers v2.step, LSM6DS33 Bracket for 7mm headers v2.stl, LSM6DS33 Bracket for 8.5mm headers v2.stl]
